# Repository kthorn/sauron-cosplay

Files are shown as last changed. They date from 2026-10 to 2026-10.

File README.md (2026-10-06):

# Child-sized Sauron mace

A **carrying/photo prop, not a striking toy**, sized for a 4′8″ child: **889 mm / 35 inches overall**, six EVA blades, nominal ¾-inch PVC, and a multi-tapered printed blade holder in **two stacked sections**, split **perpendicular to the handle axis**. These dimensions already represent approximately **¾ scale**; do not scale the STLs down again. Blade design **D ("spiked")**, adapted from the United Cutlery PD4646 drawing: sturdy body, spear tip, a round bite and a barbed opening open to the shaft, a hooked outer spike and a crescent base horn. An adaptation, not a film-exact tracing. References and fact/design distinctions: [SOURCES.md](file:///home/kurtt/sauron-cosplay/SOURCES.md) (`/home/kurtt/sauron-cosplay/SOURCES.md`).

## Foam helmet paper templates

Original, more movie-like **layered face plates and all six crown spires**, provisionally sized for a **540 mm headband**. These are **paper-fit design drawings, not measured or foam-ready patterns**. No printed helmet shell is needed.

- [US Letter PDF — five pages](file:///home/kurtt/sauron-cosplay/patterns/helmet/helmet-letter.pdf): `/home/kurtt/sauron-cosplay/patterns/helmet/helmet-letter.pdf`
- [A4 PDF — five pages](file:///home/kurtt/sauron-cosplay/patterns/helmet/helmet-a4.pdf): `/home/kurtt/sauron-cosplay/patterns/helmet/helmet-a4.pdf`
- [Preview, cut list, paper assembly, and scaling instructions](file:///home/kurtt/sauron-cosplay/patterns/helmet/README.md): `/home/kurtt/sauron-cosplay/patterns/helmet/README.md`

Print at **Actual Size / 100%** and check each 100 mm ruler. Pages 1–4 are cutting sheets; page 5 is the assembly key, **not a cutting template**. All parts fit on individual sheets at the supplied size. Full-size editable SVG masters are in `patterns/helmet/`. Paper-fit before EVA; eye position needs separate checking, and helmet sizing does not use the mace's 75% scale. Mace files and regeneration commands below remain separate and unchanged by this drawing set.

## Files

All files are under `/home/kurtt/sauron-cosplay`:

| File | Use |
|---|---|
| `mace.scad` | Editable canonical geometry; default view is assembly |
| `patterns/blade.svg` | Full-size editable pattern, 150 × 351 mm canvas; use tiled PDFs for home printing |
| `patterns/blade-a4-01.pdf`, `blade-a4-02.pdf` | **Two A4 sheets**, 210 × 297 mm each |
| `patterns/blade-letter-01.pdf`, `blade-letter-02.pdf` | **Two US Letter sheets**, 215.9 × 279.4 mm each |
| Matching numbered `.svg` files | Editable versions of the tiled sheets |
| `prints/fit-coupon.stl` | Print **one first** to test real pipe/foam fit |
| `prints/holder-lower.stl` | Print **one**, upright: lower hexagonal holder section, approximately 123 mm tall plus three 6 mm alignment pins on top |
| `prints/holder-upper.stl` | Print **one**, upright: upper hexagonal section with integrated pointed cone and three matching pin holes in its bed face, approximately 123 mm tall |
| `prints/holder.stl` | Complete approximately 246 mm holder for reference/larger printers; **too tall upright for the A1 mini** |
| `prints/adapter.stl` | Optional original ring; print two **instead of** the tapered holder |
| `patterns/manifest.json` | Parameters, holder profile/split, source fingerprints, common tile origins and owned generated files |
| `export.py`, `test_mace.py` | Regeneration and executable verification |

## Tools and regeneration

Verified here with **OpenSCAD 2021.01, Poppler 24.02.0, CairoSVG 2.9.0**. Use the Python interpreter that has CairoSVG installed (here `/home/kurtt/miniforge3/bin/python3`).

```bash
sudo apt-get install openscad poppler-utils
python3 -c 'import cairosvg'
cd /home/kurtt/sauron-cosplay
python3 export.py
python3 export.py --check
python3 -m unittest -v
openscad mace.scad
```

Measure your actual pipe OD and foam thickness before fitting. Example:

```bash
python3 export.py --set pipe_od=27 --set foam_thickness=12
python3 export.py --out "/path/with spaces"
```

`--set` overrides apply to that export, not to the saved SCAD defaults. For a matching interactive preview, set the same values in OpenSCAD's Customizer or edit `mace.scad`; edit SCAD for persistent changes. Commands can also use the script's absolute path from another cwd; default output remains this project folder. `OPENSCAD` and `PDFTOCAIRO` may select alternate executable paths. `--check` checks saved outputs without regenerating them; source edits require regeneration. Invalid sizes, missing tools and failed verification stop publication. Regeneration removes only obsolete manifest-owned files and refuses unowned filename collisions or unsafe/symlink paths.

Public millimeter parameters: `overall_length`, `blade_length`, `head_radius`, `pipe_od`, `bore_clearance`, `foam_thickness`, `slot_clearance`, `adapter_od`, `adapter_height`, `slot_root_radius`, `cover_allowance`, `land_allowance`, `coupon_height`, `tip_od`, `tip_overlap`, `tip_extension`, `tip_end_radius`, `crown_recess`, `pin_d`, `pin_length`, `pin_clearance`, `pommel_od`, `pommel_height`, `pommel_extension`. Bore clearance is on **diameter**; slot clearance is on **total width**, not per side. Changing blade length scales stations but keeps land height independent of that scale. `crown_recess` defaults to 12 mm below the EVA blade tips; `tip_end_radius` defaults to 4 mm. `tip_extension` retains the 35 mm PVC-to-blade-tip setback. `tip_od` and `tip_overlap` describe only the optional legacy foam top cap (`ring_assembly` preview). Other dimensions can require more pages; use the whole numbered set, including the caption gutter on wide heads. Incompatible core, cap, covering or neighboring-blade sizes are rejected.

## Print and tape the blade pattern

1. Choose **either the two A4 PDFs or the two Letter PDFs**, not a mixture. Print at **100% / Actual Size**, with Fit/Shrink disabled.
2. Measure the red **100 mm bar** on both sheets before trimming. Black solid lines are cuts; dashed blue lines/boxes are mounting references **not cuts**; gray crosses are alignment marks; green dash-dot lines are bevel guides, **not cuts**. These line styles remain distinguishable in grayscale.
3. Trim the **bottom 30 mm from page 1** and the **top 25 mm from page 2**. Align both gray crosses in the **10 mm overlap**, then tape. Do not simply butt whole page edges together. Discard the trimmed headers/footers only after the ruler check.
4. Check the assembled black outline: **295.275 mm tip-to-base × 46.5 mm radial width**. Cut on the black line's center. Transfer **six identical blades** onto measured 10 mm EVA. No rigid blade reinforcements.
5. Bevel using the **green dash-dot line**, 6 mm in from each exposed edge (not along the straight root edge, which sits in the grooves). It is a marking line, **not a cut**: cut the blade out square on the black line, transfer the green line to **both faces** (prick through the paper or measure 6 mm in), then carve or sand from the line to the edge on each face, leaving about a 2 mm flat in the middle of the edge. With 10 mm foam that removes about 4 mm per face, roughly a 35° bevel. Where the line stops short of a point (tip, spike, barb, horn), taper the bevel out to the point. For thinner foam, regenerate with a smaller inset, e.g. `python3 export.py --bevel 4`.
6. Test-cut one blade from scrap EVA first and check flex across the bridges beside the openings, the barb, the hooked spike and the horn. Round over every point by hand.

## Print and fit the tapered holder

The **hexagonal spindle** follows the drawing's 380 mm core: a flared base collar, a narrow waist, one widest swell, then a long taper to the crown, placed to match blade D: the collar on D's base root, the waist inside its lower opening, the swell over its solid middle root, and the taper through its round bite, so the core shows through both openings as in the drawing. Blades sit at its **six vertices**, but it is grooved **only where a blade meets the core**: D's three root contacts, about **37–67, 117–179 and 207–243 mm** from the blade base. Each groove floor follows the blade's inner edge; between the grooves the hexagon is solid. The upper section includes a **printed cone ending in a hexagonal point** (no ball tip), ending approximately **12 mm below the protruding EVA blade tips**. This is a simplified interpretation of the drawing, not a precision replica. The existing **295.275 mm blades, 180 mm station spacing, and PVC cut length are unchanged**. The complete holder is approximately **246 mm tall**, split perpendicular to the handle axis into **two approximately 123 mm sections**, joined end-to-end around the PVC. Three printed **4 mm alignment pins** on the lower section's top face (6 mm long, on the hexagon-flat directions, clear of the grooves; the joint falls inside the middle groove zone) drop into **4.4 mm blind holes** in the upper section's bed face; no screws or other hardware.

Default dimensions: pipe OD **26.67**, bore **27.17** (+0.50 diameter); foam **10**, slot **10.3** (+0.30 total width), slot roots **18.5 mm from the axis**. The swell reaches **60 mm nominal diameter** (collar 54 mm); grooves remove those vertices, so do not rescale the meshes to force a 60 mm bounding box. The waist leaves approximately **3.30 mm minimum wall** outside the cylindrical bore. The upper bore stops above the PVC end with 1 mm axial slack, then closes with a **45° internal conical ceiling**; the pointed crown above it is solid. Both sections fit well within the A1 mini's **180 × 180 × 180 mm** volume, with room for a brim.

1. Print the existing **5 mm fit coupon first**, upright. Test the real bare PVC and foam; adjust `pipe_od`, `bore_clearance`, `foam_thickness`, and `slot_clearance` rather than forcing a fit.
2. Print **one lower and one upper section**, separately or side-by-side. Import at **100% scale**, with the bore vertical and the exported Z=0 face on the bed. Keep their exported orientation; the sections are **not identical**.
3. Defaults use ascending tapers and the internal bore ceiling no steeper than approximately 45°: **no supports are intended**. The lower bore goes through; the upper bore opens only at the bottom. Inspect Bambu Studio's layer preview before printing, especially if dimensions change. PLA or PETG, 0.2 mm layers, 3–4 perimeters, 15–20% infill, and a small brim are starting settings, not strength certification.
4. Dry-fit both pieces end-to-end on the PVC, **lower first**, with all six grooves aligned and the three pins seated in the upper section's holes. If the pins bind, trim them lightly or regenerate with a larger `pin_clearance`; do not force the joint. Install **both as printed, with their bed faces toward the pommel**: the upper section's bed face is the joint, and its cone points toward the blade tips. Their flat transverse joint is located at **160.138 mm from the blade base**. The collar sits at the 45 mm station; the 60 mm swell is centered about 150 mm from the blade base, over the middle root. The PVC aligns the bores; the alignment pins establish rotation. Do not twist or force the pieces with blades fitted.
5. Bond the sections to the PVC and to each other only after checking adhesive compatibility on scraps. The butt joint is not a load-rated connection. Pad exposed hard surfaces after fitting without narrowing the grooves.

The original `adapter.stl` remains an optional lighter two-ring alternative. Do not install those rings inside the new holder. The full `holder.stl` is one connected piece but is **not the A1 mini print file**. The new holder adds plastic compared with the rings; weigh the finished mockup and check carrying comfort.

## PVC layout and assembly (defaults)

The **provisional PVC cut is 839 mm**, not 889. Dry-fit before the final cut/glue. Layout includes 15 mm solid foam below the lower pipe end. The EVA blades extend 35 mm above the upper pipe end; the pointed printed cone ends about 12 mm below those blade tips. The EVA surround is **not an impact-protection guarantee**. The top is open approximately **60 mm across**: a finger, nose or eye can reach the hard crown **without touching or deforming the foam**. Keep the head away from faces; do not let children look into or poke the crown.

| Feature | From the prop's lowest foam extremity | From the lower PVC cut end |
|---|---:|---:|
| PVC lower/upper ends | 15 / 854 mm | 0 / 839 mm |
| Blade base | 593.725 mm | 578.725 mm |
| Lower holder bottom | 630.725 mm | **615.725 mm** |
| Lower blade station center | 638.725 mm | 623.725 mm |
| Holder section joint | 753.863 mm | **738.863 mm** |
| Upper blade station center | 818.725 mm | 803.725 mm |
| Rounded printed crown tip (nominal) | 877 mm | **862 mm** |
| EVA blade tips | 889 mm | 874 mm |

If length/cap settings change, use the new manifest's `pipe_span`, `blade_base`, `stations` and parameters instead of these default marks.

1. Have an adult cut/deburr the PVC. Mark the holder's lower bottom and section joint using the table. Slip the lower and upper sections onto **bare PVC**, **bed faces toward the pommel and cone toward the blade tips**, seating the three pins in their holes, which aligns the six grooves, and closing the transverse joint.
2. Dry-fit one blade radially into the aligned grooves. Its root stops at 18.5 mm radius. Existing mounting bands remain **34–56 and 214–236 mm** from the blade base; station centers remain **45 and 225 mm**. Grooves are cut wherever the blade's inner edge would otherwise enter the spindle, so the relieved edge between the bands clears it. Check flop and clearance before cutting/gluing the other five. Thicker foam is a tuning option; regenerate the slots and recheck weight/fit.
3. Fit all six, then glue permanently using manufacturer-compatible adhesives **tested on scraps** for EVA, PVC and the chosen print plastic. Plumbing PVC solvent cement is **not assumed to bond PLA/PETG**. Follow adhesive ventilation, curing and handling directions; keep coating off bond surfaces until joined.
4. The printed crown is already part of the upper section; **do not fit the old foam top cap over it**. Check that the pipe seats without force and that the crown stays approximately 12 mm below the EVA tips along the handle axis. This axial recess does not enclose the tip or prevent direct contact through the open head. For the optional two-ring alternative only, use `ring_assembly` to preview the original foam top-cap envelope: 36 mm OD, 15 mm sleeve overlap and 35 mm solid foam above the PVC, with a blunt 4 mm-radius tip.
5. Make the **pommel cap from EVA**, 40 mm OD × 40 mm long. Its cavity opens from above, is 25 mm deep, and leaves **15 mm solid foam beneath the PVC**. Round the outside without adding to overall length.
6. Bond the foam pommel only after an adhesion/retention trial. Wrap the shaft with approximately **3 mm radial foam**, **not beneath the holder bore or pommel sleeve**; the first 25 mm of PVC seats in the pommel. Leave the PVC bare from the holder's lower bottom through the upper pipe end. Pad exposed holder edges without obstructing blade grooves; the pointed crown intentionally remains printed plastic; lightly sand the point blunt if wanted. Check blade retention and spacing so it stays recessed. Foam blades can bend or tear and must not be relied on to make a hard crown safe to strike with.

## What was verified / what was not

Digital checks: blade D's polygon is simple, its openings stay open to the shaft with at least 16 mm of foam beside them, and green bevel guides on every sheet lie inside the outline and off the root edge. Actual SVG outline **295.275 × 46.5 mm**; A4 PDF reconstruction approximately **295.27538 × 46.49914 mm**, Letter **295.27431 × 46.49914 mm** (all within 0.1 mm). The original ring and coupon remain closed connected meshes with correct 16/5 mm height, through-bore and six open slots. The whole tapered holder and both upright sections are also checked for closure/connectivity, correct cylindrical bore and conical ceiling, six vertex grooves whose floors follow the blade inner edge, with solid hexagon vertices outside the contact regions (including width checks on both sides at the blade stations, widest swell and each section's deepest groove; unverifiable groove widths are rejected), the hexagonal spindle profile, pointed crown, and approximately 246/123/123 mm heights. Section bounding boxes are checked against a **175 mm** envelope, reserving 5 mm total for a brim on the 180 mm printer. An actual CAD intersection checks the foam against the new holder, excluding nominal root-face contact. Reference centers **and band boundaries** are checked in SVG/PDF physical coordinates. The real CLI rejects 90%-scaled cut outlines while their calibration bars remain unchanged, then passes after restoration. Model/assembly and both paper-format previews were inspected; no interactive GUI editing or physical fabrication was performed.

Radial/sector/land assertions bound the entire blade foam outside the covered core/cap and within non-overlapping 60° sectors. Radial insertion keeps these clearances; seated roots pass through wider open slots. This is geometric clearance, **not** a load, cushioning, adhesive or impact test.

**Before the child uses it:** test coupon fit and compatible adhesives; assemble one blade to check flop; check holder-joint, blade and pommel retention, crown recession, and that all other hard endpoints/fittings are covered; weigh the completed mockup and check the child's carrying comfort. Check the venue's rigid-core prop rules. Adult supervision for cutting, printing, glue, heat and paint. **Do not swing or strike with this prop.** Foam dimensions are provisional, not an impact-protection rating.

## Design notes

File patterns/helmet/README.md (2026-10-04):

# Sauron helmet — printable paper-fit templates

**Provisional nominal 540 mm headband, not measured child fit. Start with paper, not EVA.** Original simplified drawings based on production-helmet photographs: layered face plates and six principal crown spires, without intricate engraving or a closed shell.

## Print these

- [US Letter PDF — five pages](file:///home/kurtt/sauron-cosplay/patterns/helmet/helmet-letter.pdf)
  `/home/kurtt/sauron-cosplay/patterns/helmet/helmet-letter.pdf`
- [A4 PDF — five pages](file:///home/kurtt/sauron-cosplay/patterns/helmet/helmet-a4.pdf)
  `/home/kurtt/sauron-cosplay/patterns/helmet/helmet-a4.pdf`
- [Assembled appearance and crown-position preview](file:///home/kurtt/sauron-cosplay/patterns/helmet/preview.png)
  `/home/kurtt/sauron-cosplay/patterns/helmet/preview.png`

Choose the PDF matching your paper. Print **Actual Size / 100%**, with Fit/Shrink disabled. Check the **100 mm red ruler on every page** before cutting. Pages 1–4 are cutting sheets; page 5 is an assembly illustration, **not a cutting template**. Each part fits on one sheet: no page trimming/taping is required at this size.

The five numbered `.svg` files beside this README are the full-size editable drawing masters, with millimeter dimensions. They use Letter canvases; the A4 PDF changes the paper size, **not the artwork scale**. The assembly illustration is schematic, with wrapped side plates compressed in front view; do not measure or trace its silhouette for cutting.

## Cut list

Cut one master per distinct outline, then trace repeats onto spare paper. For a mirrored pair, flip the master over for the second piece; alternatively print selected cutting sheets again. Black internal openings in A and B are cuts too.

| Sheet | ID | Part | Quantity | Eventual foam starting thickness, after paper fit |
|---|---|---|---:|---|
| 1 | A | Eye/brow frame | 1 | 4 mm |
| 1 | E | Brow ridge | 2 mirrored | 2 mm |
| 1 | G | Forehead accent | 1 | 2 mm |
| 1 | K | Forehead support patch | 1 | Soft 4–6 mm |
| 1 | L | Temple support tab | 2 | Soft 4–6 mm |
| 2 | B | Split center/nose ridge, with breathing slot | 1 | 4 mm |
| 2 | C | Swept cheek plate | 2 mirrored | 4 mm |
| 2 | C2 | Cheek inset | 2 mirrored | 2 mm |
| 3 | D | Temple plate | 2 mirrored | 4 mm |
| 3 | S1 | Central front spire | 1 | 4 mm |
| 3 | S2 | Central rear spire | 1 | 4 mm |
| 4 | S3 | Tall side spire | 2 mirrored | 4 mm |
| 4 | S4 | Short forward spire | 2 mirrored | 4 mm |
| 4 | H | Paper support strip | 6 | **Paper fitting aid; final support is soft webbing** |

Six spires total: **S1 + S2 + 2 × S3 + 2 × S4**. Their 25 mm roots are already included in the outlines. Do not add another root allowance. All foam thicknesses are provisional; physical stiffness, fit, and weight have not been tested.

## Line key

- **Solid black:** cut outline and openings.
- **Dashed blue:** placement or bond/overlap guides; do not cut.
- **Dash-dot green:** shallow forming fold for paper; do not cut through foam later.
- **Gray labeled diamonds:** match the same label across parts. These are adjustable lap placements, not precision edge-to-edge joints.

## First paper assembly

1. Make the support before the face. Four H strips (165 mm each) joined at three 20 mm overlaps give **600 mm**. Close with an adjustable **60 mm rear overlap** for a nominal **540 mm** loop. Two more H strips joined with 20 mm overlap give a **310 mm** top strap; provisional 20 mm end attachments leave **270 mm** over the head. Adjust on the child, keep it loose, and keep the rear overlap reachable. No chin strap.
2. Gently curve A around the face. Match A/B to place B on its center and A/C to place both C cheeks. Wrap cheeks/temples around the face; do not just add their full flat width to the front. Cut A's eyes and B's breathing slot. Tape only B's upper A/B area, leaving its lower portion free; use the short green guide below eye level to angle it gently forward, away from nose/mouth pressure.
3. Fold K at its green center line: center its face half behind A's forehead zone and tape its band half to the front band, adjusting the fold/curvature for forehead stand-off. Turn each L 90 degrees so its 25 × 20 mm half matches A's 20 × 25 mm blue side box; tape that half directly behind A and fold the other half toward the temple band. Fit L before D, then add D behind the sides using A/D without covering L's fold or band half. Use broad outside tape areas; do not hang the face from temple tabs alone. The top strap supports height but does not prove resistance to tipping. These folds do not guarantee nose clearance; fit the wearer and recheck tipping whenever stand-off changes.
4. Add E using A/E, G using B/G, and C2 using **both** C2.1 and C2.2 diamonds. Decorative overlays are optional; do not cover sight or breathing openings.
5. Form the spires into shallow open-backed V sections along the green guides, roughly 120° as a paper starting point. Curve/fold each 25 mm root to the band and tape it in the crown position shown on page 5. Add them one at a time and check balance. S2 must not tape across the rear adjustment/removal opening. Tape or round all sharp paper corners before fitting.
6. With an adult supervising, start stationary and then walk on a clear flat floor. Check floor/side vision, normal speech/breathing, nose/ear/forehead pressure, head turns/downward looking, glasses clearance if needed, shoulder clearance, crown clearance, and **unaided removal**. Stop for slipping, obstructed sight, discomfort, dizziness, or breathing difficulty. No running or stairs in this trial.

Mark corrections on the paper: eye centers, band length, cheek length, crown height, and attachment positions. A paper fit does not establish foam fit, cured bond retention, weight, point softness, or heat comfort. Recheck these independently in a future foam prototype. This is not protective headgear or a safety certification.

## Scaling later

At the supplied size, the ruler measures 100 mm. For an initial uniform paper rescale to a measured circumference H, start with **H / 540 × 100%**; the ruler then measures **100 × H / 540 mm**. This is only a starting point: eye spacing and cheek/shoulder clearance need separate fitting, not circumference scaling.

For enlargement use a PDF viewer's **Poster / Tile Scale** printing, or resize SVG canvas and artwork together in a vector editor. Ordinary custom scaling on a fixed page can clip pieces near the margins. Keep every cutting sheet at the same intended scale, verify the appropriately scaled rulers, and check for complete outlines. Do not use Fit/Shrink as a substitute for a known scale.

## Checks and limits

All 14 distinct component outlines were checked against their declared flat dimensions, including all six spires through their quantities. The actual final PDF cutting paths, blue placement paths, green forming guides, page sizes, and red rulers were compared with the SVG masters within 0.1 mm. A deliberate copied 90%-scale cutting-path corruption was rejected with its 100 mm ruler unchanged. Drawings were rendered and visually inspected. No physical assembly, wearing test, or film-exact reconstruction has been verified.

Detailed design, fitting limits, and adult-only foam work guidance: [design/build guide](file:///home/kurtt/sauron-cosplay/docs/superpowers/specs/2026-10-03-sauron-helmet-design.md).

`/home/kurtt/sauron-cosplay/docs/superpowers/specs/2026-10-03-sauron-helmet-design.md`

The SVGs—not a temporary authoring script—are the retained masters. No OpenSCAD model or permanent pattern generator was added. After editing a master, regenerate its PDF with installed CairoSVG, merge pages with installed Poppler `pdfunite`, and recheck actual PDF geometry before replacing a print pack.

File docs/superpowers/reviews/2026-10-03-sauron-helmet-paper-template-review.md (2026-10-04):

# Sauron paper templates — revision 2 review and verification

2026-10-03. Subject: original provisional paper-fit design drawings, not fitted foam fabrication or protective headgear. Parent authored/refined the documents and drawings; independent reviewer was read-only. No permanent product code or generator was added. SVGs are the retained masters.

## Review routing and scope

- Requester: OpenAI (`PI_PROVIDER=openai-codex`, `PI_MODEL=gpt-6.1-sol`). Required opposite family: Anthropic.
- Paseo agent: `0411aa0d-d3f7-4eac-b6c3-b96a4f0939dc`, cwd `/home/kurtt/sauron-cosplay`; no Git branch/ref/worktree.
- Canonical selection: `claude/claude-opus-5-5`, thinking `medium`, Plan Mode; actual model/effort/mode verified with `paseo inspect`.
- Evidence supplied: exact spec and pattern README, artifact hashes, rendered four-sheet contact image, assembly preview, production-helmet photograph, and parent physical-export verification results. Reviewer used no tools and did not independently open PDFs or confirm hashes.
- Three scrutiny areas: drawing/assembly contracts, child wearability boundaries, and printing/scaling correctness.
- Initial review plus one focused follow-up, same model/effort. First 120-second wait window elapsed while agent remained running with no error or permission request; subsequent waits returned `idle` and actual final responses were consumed. No route substitution.

Initial spec SHA256: `0b8590c9d465c1dcdfc26b38b476de809d3f1a52b45f2434a83e2522084808ef`.
Corrected reviewed spec SHA256: `514c7fe111a717fdbd355d4d9e93409dcb61457c50be77aea3933cac9e3b7f02`.
Corrected reviewed pattern README SHA256: `f367e110d07bfcda0d924104291474c485026230c0f6c42f4f85d6ebf64b5609`.

## Findings and dispositions

1. **L temple-tab placement unspecified — accepted.** A's two blue side boxes now explicitly say “L behind”; sheet 1 specifies a quarter-turn and sheet 5 names those support zones. Both documents state that a rotated 25 × 20 mm half matches the 20 × 25 mm box, attaches directly behind A, and folds toward the band. Fit L before decorative D and keep D off the fold/free band connection. Do not make D the sole support connection. Follow-up: resolved.
2. **G forehead accent slightly covered inner eye corners — verified and fixed.** Parent exact polygon check reproduced the original overlap, then checked the corrected nominal flat placement. Moved G corners `(11,35)` and `(29,35)` inward to `(14,35)` and `(26,35)`, leaving its 40 × 47 mm bounds and anchor unchanged. Both eye polygons now clear it; curved/worn clearance remains unverified. Follow-up: resolved for the drawing, with only about 1 mm nominal inner-corner margin.
3. **Forehead/nose stand-off under-specified — accepted as a practical documentation gap, not proof of physical failure.** Added K's center forming guide and face/band half labels, and B's below-eye forming guide. Documents now instruct adjustable forehead stand-off, upper-only B attachment, free lower B angled forward, physical clearance checks, and retesting tipping when the gap changes. No fixed spacer depth or guaranteed wearability was invented. Follow-up: resolved as a wording issue.

Optional footer concern addressed: caption moved from y=273 to y=269 mm, leaving at least 10.4 mm below its baseline on Letter; ruler unchanged. Other optional refinements were not blockers and did not warrant extra machinery or review rounds.

Terminal reviewer verdict: **“No supported substantive findings.”** Stop the refinement pass. Subsequent status/link/checklist additions are administrative, not changed fabrication geometry.

## Parent executable and visual verification

One-off document verification reused the existing `export.py` `_geometry`, `_segments`, `_bounds`, and `_same_segments` helpers; no parallel permanent SVG/PDF parser was created.

- All 14 distinct pieces matched independently specified flat bounding dimensions. Spire quantities total six; H quantity is six.
- Every cutting path was inside both paper formats: x ≥ 10, x ≤ 200, 30 ≤ y ≤ 253 mm.
- `pdfinfo` confirmed two five-page packs: Letter 215.9 × 279.4 mm and A4 210 × 297 mm.
- Each page of the final merged PDFs was converted with `pdftocairo -svg -f N -l N -noshrink -nocenter`; actual black cutting paths, blue placement paths, green forming guides (normalized into the existing verifier's reference channel), and red calibration paths matched the SVG masters within 0.1 mm. Page dimensions matched within 0.01 mm.
- Every actual PDF ruler measured 100 mm; `pdftotext -layout` confirmed five provisional warnings and five ruler captions in each pack.
- An intentionally copied 90%-scale A outline failed the physical cutting-path comparison while its 100 mm ruler remained unchanged. Original masters/PDFs were not mutated by the probe.
- Separate eye-overlay regression reproduced the old G/eye intersection and confirmed its absence after the inward-corner correction, at nominal flat placement only.
- Masters, both paper-format PDF examples, and assembly preview were rendered and visually inspected; revised support labels/forming guides checked after corrections.
- Final geometry checks and local Markdown link-target checks were rerun after corrections. Mace source/generated files were outside this session's changes; another session independently owns them.

## Reviewed final artifact hashes

| File under `patterns/helmet/` | SHA256 |
|---|---|
| `01-frame.svg` | `af767f6572b9c0734890af57feba7dbcecb2cd3ec6c8a10f723a10159c24d267` |
| `02-face.svg` | `3382725252666c72c9f201cab9dcb63478ff3045fbe153ee0186c93ea1d81522` |
| `03-center-spires.svg` | `dbb1086b69499819ac96594434a216da752934dc15a610ade25f1d5ef8df858a` |
| `04-paired-spires.svg` | `50a0ab4562e5bcb87f186713d14b202100e7bd1f8ca970972d0763f88d0cbb6c` |
| `05-assembly.svg` | `e8821adcfc7a0130f1c3a7f7496c50643de46906950a3c01eefae62f4a33a28b` |
| `helmet-a4.pdf` | `816ec15260dfc9612cf15b0aa74d6644776d33525473bf8debeb7226a0268954` |
| `helmet-letter.pdf` | `7b51f6a6edb09eb445059b762a55add4034b21f2655fb927945136eabe70dca1` |
| `preview.png` | `f3e375338d18b0d90b044d5efdacd2b230ce3d6e872816292a54d29f6426f05b` |

## Remaining limitations

User silhouette approval and paper fitting are pending. Nominal 540 mm circumference and 60 mm eye spacing are not child measurements. Tight nominal overlay clearance, folded support geometry, six-spire balance, and actual nose/shoulder/door clearance require the physical trial. Paper success does not establish EVA stiffness, forming, bond retention, finished weight, heat comfort, or safe impact performance. Do not go straight from this document review to foam construction without those fit checks.

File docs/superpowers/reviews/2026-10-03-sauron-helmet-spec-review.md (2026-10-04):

# Sauron foam helmet — independent design review record

Date: 2026-10-03. Mode: parent-authorized document drafting/refinement, independent **read-only text-only review**. No physical build, fitted pattern, CAD, video, or executable changes were reviewed.

## Subject and routing

- Subject: `/home/kurtt/sauron-cosplay/docs/superpowers/specs/2026-10-03-sauron-helmet-design.md`.
- Requesting family: OpenAI; session environment `PI_PROVIDER=openai-codex`, `PI_MODEL=gpt-6.1-sol`.
- Required opposite family: Anthropic.
- Runner: Paseo agent `51bccd6a-b97b-40f8-bc81-0c39e72f9e23`, cwd `/home/kurtt/sauron-cosplay`, no Git branch/ref/worktree.
- Requested canonical model: `claude/claude-opus-5-5`, thinking `medium`, Plan Mode. `paseo inspect` verified actual model `claude-opus-5-5`, effort `medium`, mode `plan`.
- Initial subject SHA256: `4f63727c2ed662a6d0e8575330925227c17a8a59cb7f75f2bf60f03335b8ea0f`.
- Corrected subject SHA256: `ba12831d190e6b9e003796fea622254f6dd949b2b10fd2044b9f4ec2392024d3`.
- Budget: three substantive areas—sizing/assembly, child wearability/safety, evidence/pattern reuse. Initial pass plus one focused follow-up with the same agent/model/effort. Both `paseo wait` results were `idle`; actual responses were consumed. No tools were used by the reviewer.

## Findings and parent disposition

### 1. Under-specified facade support and forward tipping

Location: component layout and foam assembly sequence. Reviewer identified an ambiguous forehead attachment: a parent might hang the facade from temple tabs alone. A side-to-side strap does not by itself establish pitch stability under the front-heavy foam load.

**Accepted the specification gap**, not a proven claim that every such strap layout will fail. Parent added a broad soft forehead attachment patch, required forehead plus both temple connections, and explicitly separated height support from pitch stability. The cured brow/support assembly is now tested first, then cheeks and points added incrementally. Forward tipping stops work for redesign; no painful tightening, chin strap, or unapproved additional support system is prescribed.

Follow-up: reviewer confirmed this ambiguity is resolved and physical stability remains appropriately unverified.

### 2. Unsupported attribution of resizing guidance

Location: reference evidence paragraph. The first review brief omitted resizing from its summary of verified tutorial evidence, so the reviewer questioned its attribution to the author.

**Rejected on verified source evidence.** The fetched tutorial text explicitly states: “Depending on your head size you may have to shrink or enlarge the pieces.” Source: https://thewoodlandelf.com/sauron-costume-part-2-the-helmet/; session fetch result `musykwfiqp8799`, URL index 0. No substantive body change was needed. The source also explicitly describes deliberate simplification.

Follow-up: reviewer withdrew this finding after receiving the exact source passage.

## Terminal verdict and limits

Reviewer's follow-up verdict: **“No supported substantive findings.”** Stop this review pass. Subsequent review-status/checklist additions are administrative; the reviewed fabrication design is unchanged.

This is not certification of fit, comfort, safety, adhesive retention, or suitable pattern scale. User review, actual measurements, paper fitting, incremental foam fitting, and finished-costume wear checks remain outstanding. Mace source/generated files were not part of this assignment. No source PDF was redistributed.

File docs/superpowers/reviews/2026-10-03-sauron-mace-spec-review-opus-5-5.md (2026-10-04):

# Sauron Mace Spec Review (Opus 5.5, read-only)

**Subject:** `docs/superpowers/specs/2026-10-03-sauron-mace-design.md` (SHA256 `1d7ebf40…9b50`), reviewed from the supplied text only. No tools were run. This is not physical validation.

**Default geometry checked by hand:**
- **Bore-to-slot wall:** bore radius 13.585 against slot floor 18.5 gives a minimum wall of 4.915, which meets the ≥3 requirement.
- **Wall between slots:** at r = 18.5, each 10.5 slot subtends about 33° of the 60° pitch, leaving about 8.7 mm of arc between slots.
- **Slot engagement:** 11.5 radial (18.5 to 30).
- **Adapter positions:** both adapters sit fully on the PVC. The upper adapter top is at about 826.7 and the PVC ends at 854.
- **Scale arithmetic:** 0.75 × 46.375 in = 883.44 mm, and 0.75 × 15.5 in = 295.275 mm. The 889 total and the 839 pipe length (15 to 854) are internally consistent.

## Findings

**1. No minimum inner-radius (clearance) rule for the blade profile.**
- **Evidence:** The spec requires a "relieved inner edge", and the land is at radial 18.5. Acceptance 1 bounds only "max 65 radial". Blades "slide inward radially".
- **Consequence:** Nothing stops the outline, outside the lands, from going inside the PVC radius (13.335) or the covering/tip cap. That blade could not be inserted radially. Above the pipe end (854 to 889), inward-swept tips could also collide with each other or with the tip cap. The "no intersecting adjacent blades" check does not catch blade-to-pipe or blade-to-cap intrusion.
- **Smallest fix:** Add a profile constraint and check. Inner edge radius must be ≥ 18.5 within the adapter axial spans. Elsewhere along the pipe it must be ≥ pipe OD/2 plus a covering allowance. Above the PVC it must be ≥ the tip-cap radius. Out-of-range values are rejected.

**2. Tip extension and pommel are load-bearing in the layout but have no defined geometry.**
- **Evidence:** "Overall 889 incl foam pommel/tip", "Foam tip extends 35 beyond PVC", and "soft 35mm tip extension". The outputs list contains no cap or pommel part, and the blade tips also end at 889.
- **Consequence:** The child-safety soft end and the overall length rely on an unspecified part. That part must fit inside the six blade inner edges, a gap of less than about 18.5 radius. That leaves at most about 5 mm of cap wall over a 13.3 mm pipe radius, which may not be a usable soft cap.
- **Smallest fix:** Specify the cap and pommel envelope (OD, length, material, attachment) as parameters in `mace.scad`. Include them in the clearance check from finding 1 and in the README fit sequence. They do not need patterns.

**3. Reference marks cannot leave OpenSCAD with distinct styles without duplicating coordinates.**
- **Evidence:** The script "NEVER duplicates blade coordinates", yet the patterns need "distinct cut/reference styles" with bands and station centers as "REFERENCE marks". OpenSCAD SVG export produces unstyled geometry from a single 2D mode.
- **Consequence:** The implementer will either recompute station and land positions in Python, breaking the single-source rule, or ship patterns without distinguishable reference marks.
- **Smallest fix:** Define a separate SCAD 2D mode, such as `blade_marks`, exported as its own SVG. Alternatively, have the script parse `echo()`'d derived values. `export.py` then only applies styles and tiles the pages.

**4. Scale checks don't measure the exported outline itself.**
- **Evidence:** Acceptance 1 checks the blade's dimensions. Acceptance 5 checks page dimensions, overlap, coverage, and the 100 mm bar.
- **Consequence:** The calibration bar is drawn by the export script, so it can be correct while the imported SCAD outline is mis-scaled. A px-vs-mm or 96-DPI CairoSVG unit error would pass every check and produce wrong-size foam cuts.
- **Smallest fix:** In the final SVG and PDF coordinates, assert that the outline bounding box equals 295.275 axial by 46.5 radial (18.5 to 65), within about 0.1 mm. Assert the bar is exactly 100 mm in the same space. Make the deliberate-failure check (acceptance 6) include a unit or scale corruption.

## Residual risks (not findings)
- **Untested physical fit:** EVA thickness variation, print tolerance, and PLA/PETG–EVA adhesion are unproven until the coupon and scrap tests are done, as the spec already acknowledges.
- **Blade flop:** about 158 mm of unsupported blade between the lands may flop. The one-blade test covers this.
- **Unverified tooling:** OpenSCAD is absent, so no STL or SVG behavior has been verified.

## Substantive findings
1. Blade inner-edge minimum radius and clearance against the pipe, cover and tip cap is unconstrained and unchecked.
2. Tip and pommel caps are undefined despite fixing the overall length and soft-end safety, and their fit inside the blade ring is unchecked.
3. Reference-mark export conflicts with the no-duplication rule under OpenSCAD's unstyled SVG output.
4. The exported outline scale is not discriminatingly verified; only the script-drawn calibration bar is checked.

```acceptance-report
{
  "criteriaSatisfied": [
    {
      "id": "criterion-1",
      "status": "satisfied",
      "evidence": "Concise review with four evidence-backed findings (blade inner clearance, undefined tip/pommel cap, reference-mark export vs single-source rule, exported-outline scale check), hand-checked default geometry, and residual risks"
    }
  ],
  "changedFiles": [],
  "testsAddedOrUpdated": [],
  "commandsRun": [],
  "validationOutput": [
    "Hand-checked: core wall 4.915>=3; inter-slot arc ~8.7mm at r18.5; engagement 11.5mm; upper adapter top ~826.7 < PVC end 854; 75% scale values match SOURCES"
  ],
  "residualRisks": [
    "Physical fit/adhesion/flop unverified until coupon and one-blade tests",
    "OpenSCAD not installed; no STL/SVG behavior verified",
    "Review based solely on supplied spec text; SOURCES.md not independently inspected"
  ],
  "noStagedFiles": true,
  "diffSummary": "No files changed; review text returned for host persistence to docs/superpowers/reviews/2026-10-03-sauron-mace-spec-review-opus-5-5.md",
  "reviewFindings": [
    "major: spec Acceptance 1 / Interface - no minimum blade inner-radius clearance vs PVC/cover/tip cap",
    "major: spec Dimensions/layout - 35mm tip and 15mm pommel caps undefined yet set overall length and safety",
    "major: spec Approach/Patterns - reference-mark styling vs no-duplicated-coordinates rule unresolved",
    "major: spec Acceptance 5 - exported outline scale not verified in final SVG/PDF coordinates"
  ],
  "manualNotes": "No-tools read-only run; plan-mode tool workflow not invoked per runner instructions. Final answer is the review artifact."
}
```

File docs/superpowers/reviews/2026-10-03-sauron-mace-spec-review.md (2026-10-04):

# Spec review — blocked before analysis

This is a parent-recorded infrastructure report, **not a completed review or a clean verdict**.

- Run: `49d26970-24ea-4440-a336-921df606a493`
- State: `failed`, confirmed by the supervisor status tool.
- Runner: `claude-code`, external CLI, read-only Plan Mode, no tools.
- Requested and initialized model: `claude-opus-4-6`; requested effort: high.
- Exact failure: `Failed to authenticate: OAuth session expired and could not be refreshed`.
- No model analysis was delivered; API usage was zero. There are no substantive findings to salvage.
- Cwd: `/home/kurtt/sauron-cosplay`.
- Git repository, worktree, branch, and ref: not applicable; the folder is not a Git repository.
- Source/spec fingerprints remained unchanged after the failed run:
  - `SOURCES.md`: `95b8fc3d2a6c000015938f73339c8d0db173d0df8aad06a526a3a15873ead98b`
  - `docs/superpowers/specs/2026-10-03-sauron-mace-design.md`: `1d7ebf4087739624462369d118f5dede5788ff52c5037f5f0b580f015c449b50`
- No CAD implementation or fabrication export has been started.

## Recovery boundary

The owner must re-authenticate Claude Code (`claude auth login`, confirmed available in the CLI help), then authorize a same-protocol retry. This external run cannot be resumed; retry as a new read-only `claude-code` run with the same model/effort and current subject version. Alternatively, ask the owner to approve a different review route. Do not silently switch mechanisms or count this failed run as independent review completion.

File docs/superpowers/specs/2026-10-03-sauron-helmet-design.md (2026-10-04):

# Sauron foam helmet — provisional paper-template design

Status: **paper-fit design study**, not a fitted or foam-ready fabrication pattern. Revision 2, 2026-10-03. The user requested a more movie-like middle ground, explicit spike patterns, and a provisional size that can be changed later. No helmet has been fabricated or wear-tested.

## Purpose and scope

Design original full-size paper cutting drawings for a recognizable Sauron helmet for the same nine-year-old as the mace. Use layered EVA-style face plates and six faceted crown spires, inspired by production-helmet front, side, and rear photographs. Keep an open back/top, a soft adjustable support, generous sight openings, and flexible rounded points. Omit intricate engraving, a closed dome, rigid spike cores, eye mesh, chin straps, and printing hardware.

The deliverable in this revision is **the physical design drawing set for paper fitting and user review**, not a software subsystem or a parametric CAD generator. SVGs are the editable drawing masters. PDF conversion uses existing installed tools; no new product dependencies or permanent generator are needed. No mace source, export contracts, or generated mace files should change.

## Reference and evidence boundaries

Primary reference is the Propstore production helmet, not a tracing of the Woodland Elf PDF. Five photographs were visually inspected. The movie-like features to preserve are the long split lower face, narrow center ridge, angular eye/brow frame, layered swept cheek/temple plates, and faceted spires. The six principal spires are interpreted as a tall side pair, shorter forward pair, central front spire, and central rear spire. Small edge points are decorative, not additional principal spires.

Reference links and inspection limits: [helmet references](file:///home/kurtt/sauron-cosplay/docs/helmet-references.md).

`/home/kurtt/sauron-cosplay/docs/helmet-references.md`

These perspective images are not orthographic drawings or flat developments. Every dimension below is **our provisional design choice**, not a measurement of the prop or this child. Keep links to source photographs/patterns; do not redistribute or trace third-party files. The earlier five-point Woodland Elf-inspired proposal is superseded. Its review record describes that earlier revision, not approval of this new one.

## Provisional size and scaling

| Item | Drawing assumption, not measured fit |
|---|---|
| Headband loop | 540 mm after joining and rear adjustment overlap |
| Eye center spacing | 60 mm nominal; actual sight openings must be located on the wearer |
| Brow frame development | 170 mm wide; shallow wrapping changes its apparent front width |
| Central face ridge | 42 × 210 mm flat outline; narrow through the eye region |
| Main cheek plate | 70 × 196 mm flat outline, cut twice mirrored |
| Tall side spires | 50 × 205 mm, including a 25 mm root; cut twice mirrored |
| Short forward spires | 44 × 155 mm, including a 25 mm root; cut twice mirrored |
| Central front spire | 42 × 185 mm, including a 25 mm root; cut once |
| Central rear spire | 42 × 175 mm, including a 25 mm root; cut once |

A nominal 540 mm circumference is a convenient provisional size, **not an age-based recommendation**. The mask's eye openings, cheek clearance, band tension, spire length/stiffness, and support balance remain to be fitted independently.

For an initial uniform paper trial, print all cutting sheets at the same percentage. If a measured headband path is H mm, H/540 × 100% is only a starting scale, not proof of facial fit. A 100 mm scale ruler then prints at 100 × that factor mm; do not demand 100 mm after deliberately scaling. At the supplied 100% print setting, it must measure 100 mm. Record changes on the paper masters. Changing eye spacing requires moving/enlarging openings, not blindly applying circumference scale. For enlargement use Poster/Tile Scale printing or resize the SVG canvas and artwork together; ordinary scaling on a fixed sheet may clip parts near the margins. Keep paper-fitting mandatory before foam.

## Drawing set

Create four cutting-sheet SVG masters under `patterns/helmet/`, each in millimeters on a Letter-sized canvas. All pieces fit wholly on their sheet and inside the A4 printable area; **no piece spans pages**, so unnecessary page tiling/taping is avoided. Make five-page Letter and A4 PDF packs containing the four cutting sheets plus an assembly key. In the A4 pack, change paper dimensions without scaling artwork. Include an assembled preview PNG for quick visual review.

| Sheet | IDs / contents | Cut quantities for one helmet |
|---|---|---|
| 01 | A eye/brow frame; E brow ridge; G forehead accent; K forehead support patch; L temple support tab | A ×1; E ×2 mirrored; G ×1; K ×1; L ×2 |
| 02 | B central split face ridge; C main cheek; C2 cheek inset | B ×1; C ×2 mirrored; C2 ×2 mirrored |
| 03 | D swept temple plate; S1 central front spire; S2 central rear spire | D ×2 mirrored; S1 ×1; S2 ×1 |
| 04 | S3 tall side spire; S4 short forward spire; H paper support strip | S3 ×2 mirrored; S4 ×2 mirrored; H ×6 for the paper support |
| 05 | Assembly key: front illustration and crown positions | Reference only; **not a cutting sheet or an orthographic assembly projection** |

One template is provided per distinct shape. For mirrored pairs, trace onto spare paper and flip the template for the second piece; print selected pages again if preferred. Do not turn a drawn front silhouette into a cutting pattern: the flat components and assembled illustration are deliberately separate.

Solid black lines are cuts, including eye and breathing openings. Dashed blue lines are placement/bond-zone references, not cuts. Dash-dot green lines indicate a shallow paper forming fold, not a foam knife cut. Gray labeled diamonds are matching placement anchors; alignment remains adjustable during fitting. Use line styles and labels as well as colors for grayscale printing. Show ID, quantity, mirroring, and eventual foam thickness on every shape's sheet. Every PDF page carries **PAPER FIT ONLY**, the nominal size, print instruction, and a 100 mm physical scale ruler.

## Paper support and component assembly

Use light cardstock/paper, a ruler, scissors, and tape. Adult supervision; cover sharp paper edges, and do not put pins/staples near the wearer.

1. Cut six copies of H, a 25 × 165 mm paper strip. Four strips make the band: join three seams with 20 mm overlap, giving 600 mm developed length; a separate 60 mm adjustable rear overlap gives a 540 mm loop. Two further strips joined with 20 mm overlap give a 310 mm over-head strap. Its provisional 20 mm attachment at each end leaves a 270 mm over-head span. Adjust on the actual child rather than forcing these dimensions. Paper tape closures should open easily.
2. Fit band and side-to-side over-head strap loosely. The child must be able to lift them off and reach the rear overlap. This strap locates band height; it does not establish stability against forward mask weight.
3. Curve A gently around the face and place B over its center using the A/B anchor. B is narrow at eye level to avoid covering A's eye openings, with a split lower outline and a separate breathing slot. Tape B's upper A/B area only; leave its lower portion free. The short forming guide below eye level allows a gentle forward angle away from the nose/mouth. Fold K to establish an adjustable forehead stand-off instead of laying the facade directly against the forehead. These paper adjustments do not guarantee clearance: fit the actual child, and recheck tipping when the gap changes. Enlarge or shorten anything that obstructs breathing or sight.
4. Attach C to each side at the A/C anchor; wrap it toward the side, rather than treating its entire flat width as added frontal width. Attach D behind the cheek/frame at the A/D anchor. Where plates overlap, temporarily tape a small contact area on the outside. These are adjustable lap placements, not precision edge-to-edge seams. Keep the back open.
5. Fold K along its center guide: center its face half behind A in the marked forehead zone, and tape its band half to the front band, bending as needed to establish clearance. Rotate each L a quarter-turn so a 25 × 20 mm half matches A's 20 × 25 mm blue side box; tape that half directly behind A and fold the other toward the band at the temple. Attach L before D, and position D behind the sides without covering L's fold or free band half; D is decoration, not the only support attachment. Use broad outside tape contact areas. Forehead **and** temple attachment are required; do not hang the face from two temple tabs alone. Add small soft pads only if necessary and keep sight openings clear.
6. Add E and G only after basic fitting. Place C2 using its two C/C2 anchors, lining up the corresponding diamonds on C. These are decorative overlay pieces; they must not cover the eyes, breathing slot, or removal path. Overlays can be omitted if too bulky.
7. Gently form S1–S4 along their center guides into shallow open-backed V sections; a roughly 120° interior angle is an aesthetic paper starting point, not a calibrated requirement. Roots are 25 mm long. Fold/curve the root to suit its crown position, then tape it to the support with the root allowance overlapping the band. **Do not add the 25 mm root again** to the cut outline. The six positions are S1 front center, S4 left/right forward, S3 left/right sides, S2 rear center. Points can lean outward slightly, but check overhead clearance and balance.
8. Add points incrementally, testing whether the paper facade tips or slips toward the eyes. All principal spires have visibly blunted ends, not mathematical needle tips. Paper may still have sharp corners on crests, cheeks, or other edges; tape or round them further for fitting. If unstable, stop and revise the support rather than tightening painfully or adding a chin strap.

Assembly illustrations communicate layers and approximate placement, **not verified 3D joint geometry**. The rear center root must mount beside/above the reachable rear band overlap, not tape across it; the release/removal path stays clear. No closed rear shell is required.

## Eventual EVA construction, after fitting

Tentative materials: 4 mm EVA for A–D and spires, 2 mm for E/G/C2, soft 4–6 mm EVA for support patches, approximately 25 mm soft webbing for the final support. Those are starting choices, not stiffness/comfort specifications. Thin 4 mm spires may fold: shorten/widen them before considering heavier foam. No wire, rods, dowels, resin, or hardened coating.

The paper H strips are **support fitting aids**, not instructions to make the final wearable band out of cardstock or long stiff EVA strips. Transfer the accepted support lengths to adjustable webbing, sew webbing joints, and bond foam through broad manufacturer-compatible scrap-tested patches. Rear hook-and-loop must be reachable without catching hair. No chin/neck strap.

Paper crease lines are forming guides. Foam can be heat-shaped off the child to a shallow ridge; do not cut through the center line. Do not treat paper folds as a tested EVA development. Round all exposed nose, cheek, and spire edges, and test the first cured foam brow/support before adding cheeks and points. Repeat fitting after every substantial addition. No hot glue or heat shaping on the wearer. An adult handles cutting, heat, solvent adhesives, and painting with manufacturer ventilation/PPE/fire precautions; keep the child away from the work area.

Finish only after physical fitting passes. Use flexible compatible coatings, black/dark gunmetal and restrained silver edge highlights, not a hard resin shell. Fully cure/ventilate adhesives and coatings to their instructions before wear; odor absence is not a cure test.

## Acceptance and verification

Document checks must verify:

- All four masters have the intended physical millimeter sizes and quantity labels, including all six principal spires via the cut list.
- Black cutting geometry is wholly within each page, with no component clipped or split, and IDs/placement marks remain legible.
- Final Letter and A4 PDF pages have the correct paper dimensions and reproduce actual cutting-path segments and placement/fold references at the same physical scale. Checking only the separate ruler is insufficient.
- Every page has its 100 mm ruler and provisional warning. Deliberately distort a copied cutting path while leaving the ruler unchanged; the physical-geometry comparison must fail before trusting it.
- Front illustration and crown-position diagram agree with the cut IDs/counts, with illustration explicitly labeled not to cut. Render and inspect pages visually; quantitative checks do not prove a usable drawing.

Physical checks remain unverified until the child tries the paper and then the foam version. Begin stationary, then supervised walking on a clear flat floor; no running/stair trial. Stop immediately for discomfort, dizziness, breathing difficulty, blocked vision, or instability. Check floor/peripheral sight, speech/breathing, head turns/downward look, glasses clearance if relevant, forehead/nose/ear pressure, independent removal, crown/body/door clearance, and alignment. The whole costume can change shoulder clearance. Later foam wear trials must separately check cured joint retention, finished weight/balance, flex/softness, and heat buildup; a brief indoor trial does not establish long-event comfort. This is not protective headgear or a safety certification.

## Independent drawing review

Opus 5.5 reviewed this revision's exact text and rendered drawings, then a focused correction for temple-tab placement, forehead-accent eye clearance, and adjustable forehead/nose stand-off. The follow-up returned **“No supported substantive findings.”** This does not establish physical fit. Parent checks of the actual final PDF geometry, the failing scale-corruption probe, and finding dispositions are recorded in the [paper-template review](file:///home/kurtt/sauron-cosplay/docs/superpowers/reviews/2026-10-03-sauron-helmet-paper-template-review.md).

`/home/kurtt/sauron-cosplay/docs/superpowers/reviews/2026-10-03-sauron-helmet-paper-template-review.md`

## Approval boundary and progress

The user approved provisional paper sizing and the proposed more movie-like direction. These drawings remain **design-review/paper-fit artifacts**, not authorization to claim a fitted helmet or go straight to foam construction. Review the drawings and paper fit before producing a measured final pattern or implementing a parametric generator. No Git initialization is required; this folder has no Git metadata.

- [x] Confirm provisional rather than measured sizing with the user.
- [x] Inspect production-helmet photographs and define six principal spire positions.
- [x] Specify original flat pieces, paper support arithmetic, print format, and fit limits.
- [x] Create provisional full-size drawing masters and PDF packs.
- [x] Check exported physical geometry and visually inspect the sheets.
- [x] Independently review this exact design/drawing revision.
- [ ] User reviews drawings and paper fit; record dimensions and corrections.
- [ ] Create a measured final pattern and build/wear-test foam after fitting.

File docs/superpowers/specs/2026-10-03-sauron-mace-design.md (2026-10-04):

# Child-sized Sauron mace: blade patterns and adapters

Status: approved by the user on 2026-10-03; implementation plan written, execution-method selection and tool installation pending.

## Purpose and scope

Create editable cutting patterns and printable adapters for an approximately three-quarter-scale Sauron cosplay mace carried by a 4′8″ nine-year-old. Preserve the approved construction: approximately 35 inches overall, nominal ¾-inch PVC, six EVA-foam blades, two small printed adapters, and permanent glued assembly. Keep exposed tips soft and weight low, especially at the head.

Deliver the blade outline, adapter, fit coupon, assembly preview, print-ready patterns, and concise fabrication instructions. This is a carrying/photo prop, not a striking toy. Film-exact engraving, a complete printed handle, armor, removable joints, and load-bearing/impact certification are outside this first build.

## Selected modeling approach

Use **one parametric OpenSCAD file** as the canonical geometric source. It supplies a 2D blade outline and 3D adapter/preview geometry. A small export script invokes OpenSCAD and uses the already-installed CairoSVG package to make printable PDF pages from the exported SVG; it must not contain a second copy of the blade coordinates or mounting dimensions.

A `metadata` mode emits tagged, machine-readable `echo()` data with derived blade bounds, station centers, mounting-band extents, dimensions, and the model-to-SVG axis convention (radial X maps to SVG X; positive axial distance maps to negative SVG Y). `export.py` honors that transform and the native SVG `viewBox`, then adds dashed reference marks, labels, and the calibration bar in the same coordinate space. It must not recalculate station positions from independent constants or fit the outline and marks to separate bounding boxes. This resolves OpenSCAD's unstyled SVG output without duplicating geometric definitions.

Alternatives considered:

- Hand-authored SVG plus separate OpenSCAD adapters: fewer export steps, but duplicates the mounting dimensions and risks a pattern/adapter mismatch.
- CadQuery or another Python solid-modeling stack: capable, but adds a substantial dependency for two simple slotted rings.

OpenSCAD gives native SVG and STL exports and an interactive preview with little project infrastructure. No framework or package scaffolding is needed.

## Initial dimensions and coordinate contract

All CAD dimensions are millimeters. Nominal values are starting points, not verified printer fits.

| Parameter | Initial value / meaning |
|---|---|
| Overall prop length | 889 mm (35 inches), including foam pommel and tip |
| Blade axial length | 295.275 mm, rounded only for display |
| Nominal head diameter | 130 mm across opposed blade radial centerlines; an adjustable project choice, not a verified replica dimension. Foam thickness slightly increases the circumscribed envelope. |
| Pipe OD | 26.67 mm; replace with actual measured OD |
| Pipe bore clearance | +0.50 mm on **diameter**, initially |
| Foam thickness | 10 mm; replace with measured foam thickness |
| Foam slot clearance | +0.50 mm on **total width**, initially |
| Blade count | Six; centers spaced 60 degrees |
| Adapter outside diameter | 60 mm |
| Adapter axial height | 16 mm |
| Slot inner radial coordinate | 18.5 mm from the pipe axis |
| Slot outer opening | Through the adapter's outer perimeter, nominal radius 30 mm |
| Adapter station centers | 45 mm and 225 mm from the blade's lower end |
| Minimum core wall | At least 3 mm from bore surface to any slot |
| Foam tip extension past PVC end | 35 mm |
| Foam beyond PVC at pommel end | 15 mm |
| Shaft foam-covering allowance | 3 mm radially, outside adapter/cap seating areas |
| Blade-to-cover/cap clearance | At least 0.5 mm radially |
| Top foam cap | 36 mm maximum OD; 15 mm sleeve overlap plus 35 mm soft extension; blunt tip radius 3 mm |
| Foam pommel cap | 40 mm OD and 40 mm axial length; 25 mm sleeve overlap plus 15 mm solid foam beyond PVC |

The blade's 2D coordinates are **radial distance from the pipe axis** and **axial distance from the blade's lower end**. The 3D adapter's bore runs along the assembly axis. Preview extrusion of each blade is centered on its radial plane, so a 10 mm blade fits a 10.5 mm slot.

For the default length layout: blade lower end is at 593.725 mm from the pommel extremity, blade tip at 889 mm, PVC starts at 15 mm and ends at 854 mm. The corresponding provisional PVC cut length is **839 mm**, not 889 mm. Dry-fit first; optional pommel decoration must stay inside the chosen overall envelope or explicitly update it.

Changing blade length rescales its axial features, including the two mounting stations. Changing pipe OD or foam thickness does **not** uniformly rescale the prop. Derived geometry must preserve the mounting contract or reject an incompatible configuration clearly.

## Blade and adapter interface

Create a recognizable, simplified Sauron blade silhouette using the United Cutlery drawing linked in `SOURCES.md`. It is an original approximation, not a precision tracing of the low-resolution reference. Prioritize the elongated profile, swept outer lobes, and relieved inner edge over engraving. Use six identical blades; do not cut sharp rigid reinforcements into their outer points.

At each adapter station, the inner blade edge includes a **straight mounting land at radial coordinate 18.5 mm**. Each land spans the full adapter height plus 3 mm at either end: 22 mm total. Throughout that band, the blade extends radially beyond the adapter perimeter. Neither an inner-edge relief nor an outer notch may cut into this required material. Show the bands and adapter-center marks on the printed pattern as reference marks, **not additional cut lines**.

Keep the **entire blade outline at or outside the slot's inner radial coordinate**, not just the mounting lands. Inner-edge reliefs move away from the axis; no blade tip curls inward. The default minimum radius is therefore 18.5 mm and the maximum is 65 mm, giving a 46.5 mm radial outline width. Also require clearance from the covered pipe and the top foam-cap envelope along their full axial spans. Reject pipe, covering, cap, or blade configurations that overlap or leave less than the stated 0.5 mm clearance; a radial insertion path from outside must remain clear except for intended contact inside the slots.

The same adapter STL is printed twice. It is a cylindrical ring with a continuous bore wall and six straight radial slots open to the outside, extending through the adapter height. The foam roots slide inward into these slots and stop at the inner radial coordinate. No dovetails, clips, fasteners, or inaccessible internal cavities are needed.

Dry-fit both rings on the PVC, aligned at the same angular orientation and correct station spacing. Insert all six blades radially before permanent gluing. Cover visible plastic after fitting; foam covering must not occupy the bore or blade slots and invalidate their measured fit.

Print rings with the bore axis vertical, flat on the bed. Through-slots and the vertical bore should require no supports. Use a thin, approximately 5 mm-high version of the same ring as the fit coupon; it exercises both the real bore and the real six-slot geometry.

## Foam end-cap envelopes

Represent both end caps in the OpenSCAD assembly and clearance checks, **not as printed parts**. Their dimensions are provisional project choices, not verified impact-protection requirements. Make them from stacked EVA and hand-shape them; exact decorative cap patterns are unnecessary for this first build.

- **Top cap:** a 36 mm-OD cylindrical foam sleeve overlaps the bare pipe by 15 mm, ending at the PVC endpoint. Above it, 35 mm of solid foam tapers to a blunt 3 mm-radius tip. The sleeve's nominal cavity uses the same 27.17 mm fit diameter, giving approximately 4.4 mm of side foam. In blade-local coordinates the cap occupies 245.275–295.275 mm; only its first 15 mm has a pipe cavity. Its maximum radius is 18 mm, leaving 0.5 mm to the blade roots. The cap starts 9.275 mm above the upper mounting band's end, so it does not intrude into the adapter or land. Changed configurations must preserve this separation or fail explicitly.
- **Pommel cap:** a simple 40 mm-OD, 40 mm-long foam envelope occupies global axial coordinates 0–40 mm. Its cavity opens at the upper end and stops at 15 mm, so the PVC begins at 15 mm and the lowest 15 mm remains solid foam. It is well below the blade region. Round its outside during finishing without extending past the specified axial extremity.

Glue compatible foam caps to the bare pipe only after a scrap adhesion test. Cut the actual foam cavities to suit the measured pipe; modeled clearances do not establish adhesion or cushioning performance. Shaft wrapping stops before the cap sleeves and adapter bores; do not layer wrapping under a part designed to fit bare PVC. Cover the adapters' exposed surfaces after blade seating, without blocking slots. Verify cap retention, no exposed hard endpoints, and carrying comfort in the physical mockup. If adequate padding requires larger envelopes, update the model and recheck blade clearance rather than squeezing an oversized cap into the existing head.

## Files and outputs

- `mace.scad`: source model with selectable `blade_2d`, `metadata`, `adapter`, `fit_coupon`, and `assembly` modes, including parameterized foam-cap envelopes in the assembly; assembly is the normal preview, never the fabrication STL.
- `export.py`: a small export entry point; uses an available OpenSCAD executable and CairoSVG. Missing tools or failed renders are explicit errors, not placeholder output.
- `patterns/`: one full-size SVG and tiled printable SVG/PDF pages for **A4 and US Letter**. Individual numbered PDF pages are acceptable; no PDF-merging dependency is necessary.
- `prints/`: separate adapter and fit-coupon STLs, only after successful OpenSCAD rendering and checks.
- `README.md`: dimensions, adjustable parameters, regeneration command, print settings, fit-check sequence, provisional pipe cut layout, assembly, and practical limitations.
- `SOURCES.md`: URLs, verified dimensions, indexed-only leads, and the distinction between sourced facts and our choices.
- One small executable check for the geometry and export contract; use existing tools or standard-library checks, not a new test framework.

Tile at actual physical scale with at least 10 mm printer margins and 10 mm overlap. Pages need format/page identification, alignment marks, clear cut versus mounting-reference line styles, and a **100 mm calibration bar** on a page where it fits. Numbered pages must use a common coordinate origin so taping them together does not shift the blade outline. Print at 100% / Actual Size; verify the bar with a ruler before cutting foam. Parameter changes that require more pages must produce more pages, not clip or shrink the pattern.

## Verification and physical acceptance

Digital checks must establish:

1. Default blade bounds are axial 0–295.275 mm and radial 18.5–65 mm; the outline is a valid, non-self-intersecting single region. The full foam volume and its radial insertion path clear the pipe, wrapping, and cap envelopes; adjacent blades do not intersect. Ignore only the intended seated blade/slot contacts.
2. All six slot positions and both blade mounting lands agree in the assembly coordinate system. Lands encompass the full station height, including the stated allowance. Exported metadata and reference marks use these same model coordinates.
3. Default bore is 27.17 mm and default slot width is 10.5 mm; at least 3 mm of core wall remains. Covered-pipe and cap clearance is at least 0.5 mm; the top cap does not overlap either adapter or mounting band. A changed pipe OD, foam thickness, covering, or cap envelope either works coherently or fails explicitly. Mounting lands retain their required absolute height when blade length changes; reject a blade too short to accommodate the lands and caps.
4. The two fabrication STL modes render as nonempty single connected solids with a through-bore and open slots; assembly-only geometry, including foam caps, cannot enter their files.
5. Tiled page dimensions, overlap, complete outline coverage, and the 100 mm bar are preserved in SVG and PDF exports. A4 and Letter dimensions are not interchangeable. **Measure the exported blade path itself**, excluding reference marks: default physical bounding-box size must be 295.275 mm axial by 46.5 mm radial, within 0.1 mm. Measure this in final SVG physical units and final PDF page/path coordinates; for tiles, reconstruct bounds using the recorded common-origin offsets. Compare against model-derived bounds for nondefault configurations. A correctly sized script-drawn bar alone does not verify outline scale.
6. The check demonstrably fails on an intentionally invalid configuration or broken expectation, then passes after restoration. Include a deliberate outline-unit/scale corruption with the calibration bar unchanged, proving the exported-outline measurement binds.

Physical acceptance remains separate: print the coupon, check the actual PVC and foam, assemble one blade temporarily, check flop and adhesive compatibility, then let the child try carrying the mockup. Weigh the finished prop. Adjust clearance and foam thickness before committing to all six blades. Neither a rendered STL nor a passing geometric check proves carrying comfort or joint strength.

Printed adapters are not PVC fittings: do not assume plumbing PVC solvent cement bonds PLA or PETG. Select adhesive by its manufacturer's material compatibility, test on scraps, and have an adult handle cutting, printing, adhesives, heat, and finishing. Pad/cap both pipe ends, maintain the soft tip extension, cover visible hard edges, and check the venue's rigid-core prop rules.

## Current environment and approval boundary

The project folder began empty and is **not a Git repository**, so no design commit is possible without separately initializing one. Do not initialize Git merely to satisfy a workflow checkbox.

Python, Pillow, and CairoSVG are available; **OpenSCAD is not installed**. Source creation does not justify claiming STL verification. The implementation plan must establish how to run OpenSCAD (approved installation or an operator-provided executable) before fabrication exports can be accepted.

### Review disposition

Opus 5.5's first completed text-only review covered spec SHA256 `1d7ebf4087739624462369d118f5dede5788ff52c5037f5f0b580f015c449b50`. The parent verified the dimensional arithmetic and accepted the four practical gaps:

1. **Inner clearance:** bound the complete profile outside the slot roots and explicitly check pipe, covering, cap, and insertion-path clearance.
2. **Unspecified end caps:** define adjustable foam-only envelopes and their seating/padding layout. The earlier spec already required padded endpoints; this clarifies them without adding printed cap parts. These are not proven safety dimensions.
3. **Reference export:** explicitly use OpenSCAD-derived metadata for styled reference marks. Distinct styling was possible, but its single-source mechanism had not been specified.
4. **Export scale:** measure the actual final blade path, not merely the separate calibration bar; include a scale-corruption negative check. The default 46.5 mm width follows the newly explicit radial bounds, not a replica measurement.

Numerical check: bore 27.17 mm; bore-to-slot wall 4.915 mm; top cap sleeve wall approximately 4.415 mm; cap-to-blade radial clearance 0.5 mm; cap begins 9.275 mm beyond the upper land. CAD rendering and physical suitability remain unverified.

The focused follow-up reviewed the corrected contract at spec SHA256 `c048bce92aa7e4a3f95775044a6f5e4299d1ce62e22a682293e7fb55ad193551` and returned **“No supported substantive findings.”** Run `0fdb18da-ab39-4821-a7e7-fe98632839d7` completed using verified `claude-opus-5-5`, requested medium effort, read-only Plan Mode with no tools. The review was of the supplied corrected-spec packet, not executable CAD or physical fit. Remaining cap tolerance, retention, and tooling uncertainties are covered by the implementation and mockup checks above. This record and the checklist update are administrative changes after that reviewed version; the geometric contract is unchanged. Stop the refinement pass and request user approval.

### Process checklist

- [x] Capture approved physical intent and permanent assembly decision.
- [x] Inspect the project folder, tools, and dimensional sources.
- [x] Compare modeling approaches and write the geometric interface contract.
- [x] Record sources and distinguish project choices from verified dimensions.
- [x] Self-review dimensions, fit-clearance definitions, coordinate agreement, and approval boundaries.
- [x] Receive the first completed independent spec review and verify/dispose its findings.
- [x] Recheck the substantive corrections with Opus 5.5 at medium effort: no supported substantive findings.
- [x] Obtain user approval of this written spec on 2026-10-03.
- [x] Write and self-review `docs/superpowers/plans/2026-10-03-sauron-mace-implementation.md`.
- [ ] Obtain user review of the plan and execution-method selection.
- [ ] Implement, verify exports, and document physical checks.

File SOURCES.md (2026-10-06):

# Sauron cosplay mace — sources

Research recorded: 2026-10-03. This is a lightweight carrying/photo prop for a 4′8″ nine-year-old, not a striking toy. The intended build is approximately 35 inches overall, with a nominal ¾-inch PVC core, six EVA-foam blades, and a split tapered printed blade holder (the original two-ring adapters remain an alternative).

## Dimensional and visual references

### United Cutlery — The Mace of Sauron and the One Ring, UC3034

- URL: https://www.unitedcutlery.com/ProductDetail.aspx?c=&itemno=UC3034
- Evidence: manufacturer's product description, fetched directly.
- Published dimensions: **46⅜ inches overall; 15½-inch blades**.
- At 75%: **883.44 mm / 34.781 inches overall; 295.275 mm / 11.625-inch blades**.
- Use: principal length reference. The proposed build rounds the overall length to **889 mm / 35 inches**, but retains approximately **295.3 mm** blades.
- Limitation: this describes a steel-reinforced polyresin display replica, not a child-safe foam construction. Its materials are not our build recipe.

### United Cutlery drawing published by TheOneRing.net

- Article: https://www.theonering.net/torwp/2015/03/02/97253-beyond-middle-earth-united-cutlery-brings-the-hobbit-and-lord-of-the-rings-weapons-to-life/
- Drawing: http://www-images.theonering.org/torwp/wp-content/uploads/2015/02/PD4646-Mace-of-Sauron-Drawing_s.jpg
- Evidence: article fetched directly; the drawing was visually inspected during the initial research.
- Use: six-blade arrangement, blade silhouette, shaft sections, and decorative motifs.
- Limitation: the published image is only 864 × 382 pixels. Small annotations are difficult to read. The earlier approximately 45⅞-inch interpretation of the drawing differs slightly from the production replica specification above; use the manufacturer's explicit dimensions for lengths.
- Any new cutting pattern will be an **approximation inspired by this drawing**, not a precision film-prop tracing. Do not treat a chosen head width or mounting detail as a sourced dimension.

## Foam construction and existing patterns

### Storm the Castle / Will Kalif — Make Sauron's Mace

- Tutorial, part 1: https://stormthecastle.com/how-to-make-a/saurons-mace.htm
- Tutorial, part 2: https://stormthecastle.com/how-to-make-a/saurons-mace2.htm
- Free three-page pattern PDF: https://stormthecastle.com/how-to-make-a/saurons-mace/saurons-mace-pdf.pdf
- Evidence: both tutorial pages fetched directly; the PDF was successfully fetched and identified as three pages. Its cutting geometry has not been measured.
- Published construction: approximately 24-inch broomstick, six foam-board blades, cardboard fittings, and a lightweight pommel.
- Use: accessible construction reference and an existing simplified blade pattern.
- Limitations: foam board is not EVA; this is a simplified craft interpretation. Its template is not established as a full-size replica pattern. **Do not assume printing it at 75% produces our intended blade size.**

### Instructables — Sauron's Mace From Lord of the Rings

- URL: https://www.instructables.com/Saurons-Mace-From-Lord-of-the-Rings-2/
- Evidence: found in search; direct fetch failed because the page appears JavaScript-rendered.
- Use: additional construction lead. Not an independently verified dimensional reference.

## Existing printable models

### MakerWorld — Sauron's Mace, model 477771

- URL: https://makerworld.com/en/models/477771-sauron-s-mace
- Alternative listing: https://www.thingiverse.com/thing:6652328
- Evidence: indexed descriptions; MakerWorld direct fetch was blocked by HTTP 403. Downloadable CAD/mesh files and licensing have **not** been inspected.
- Indexed description: V2 accommodates nominal **½-inch PVC** throughout the model; the complete printed mace is approximately 46 inches long. The listing warns that a fully printed version can weigh upwards of 2 kg.
- Use: assembly reference and possible inspiration for shaft decoration.
- Limitations: not a ready-made EVA adapter kit, and not designed for our ¾-inch pipe. Uniformly scaling the model also changes its bore. Verify the version, geometry, and license before reuse or redistribution.

### Printables — Sauron's Mace by Nikoraasu

- URL: https://www.printables.com/model/588352-saurons-mace
- Evidence: indexed description; direct fetch was blocked by HTTP 403. Model files and licensing have **not** been inspected.
- Indexed description: **16 mm central bore** for a reinforcing stick, plus two 5 mm holes for additional anti-rotation rods.
- Use: alternative shape/assembly reference.
- Limitation: a 16 mm bore does not accommodate our selected 26.67 mm outside-diameter pipe. Do not adopt the extra rods for this child-oriented foam prop by default.

## Pipe dimensions

### Wavin — PVC Pipe Schedule 40, ASTM D1785

- Datasheet: https://wavin.us/hubfs/Product%20Literature/PVC%20Schedule%2040/SS%20-%20PVC%20Sch%2040.pdf
- Evidence: three-page manufacturer PDF fetched and its extracted text inspected; see Table 1.
- Nominal ¾-inch pipe: **1.050 inches / 26.67 mm OD**, **0.113 inches / 2.87 mm wall**.
- Nominal ½-inch pipe: **0.840 inches / 21.34 mm OD**, **0.109 inches / 2.77 mm wall**.
- Use: initial adapter bore sizing. These figures describe US nominal Schedule 40 plumbing PVC; other pipe systems may differ.
- **Measure the actual purchased pipe**, then print a fit coupon. Nominal size is not outside diameter; printer and pipe tolerances are not established by this datasheet.
- Earlier pipe-weight figures were rough estimates, not measured build weights or values verified in this datasheet. Weigh the actual core and finished assembly.

## Project choices, not sourced facts

The following are our design decisions rather than claims from the references:

- 35-inch / 889 mm overall target and permanent glued assembly.
- Nominal ¾-inch PVC core; nominal 10 mm EVA as the initial blade material.
- Blade design D ("spiked"): an adaptation of the drawing's blade side view (sturdy body, spear tip, round bite, barbed opening, hooked outer spike, crescent base horn), fitted to the existing ~3/4-scale 295.275 × 46.5 mm envelope and mounting bands. Feature sizes are project choices, not measured drawing dimensions.
- A hexagonal spindle holder following the drawing's 380 mm core silhouette (base collar, waist, single swell, long taper), with blade grooves at its six vertices only where the blades meet it, and an integrated pointed printed crown (ball tip removed at the user's request), recessed 12 mm below the EVA blade tips. Total height approximately 246 mm, split perpendicular to the handle axis into two approximately 123 mm sections for an A1 mini. Proportions, clearances and the transverse split are project choices, not measured drawing dimensions. The existing blade shape, 180 mm mounting-station spacing and PVC layout are retained; no second 75% scaling is applied.
- A small fit-test print and optional original two-ring alternative; adapter OD 60 mm, height 16 mm, slot roots at radius 18.5 mm.
- Nominal head span 130 mm across opposed blade centerlines; the cutting outline has initial radial bounds 18.5–65 mm.
- Independently adjustable pipe clearance, foam-slot clearance, blade length, and head width.
- Soft EVA blades and pommel, with a rounded hard crown intentionally recessed inside the blades as requested by the user. This does not establish impact protection: the blades can bend or tear. The pommel is 40 mm OD × 40 mm long, including 15 mm solid foam beyond the PVC. For the optional two-ring build only, the legacy foam top cap has 36 mm maximum OD, 15 mm sleeve overlap and 35 mm soft extension. These are geometric starting choices, not validated protection dimensions.

Digital fit checks cannot establish adhesive strength, foam stiffness, carrying comfort, or suitability under an event's prop rules. Validate these with a physical coupon and a one-blade mockup before cutting all six blades or gluing the final assembly.

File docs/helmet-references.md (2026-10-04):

# Sauron helmet — references for original printable EVA templates

Research: 2026-10-03. Requested direction: a middle ground between the Woodland Elf craft version and highly detailed replicas, with a more movie-like silhouette and explicit printable patterns for all crown spikes. Wearer remains the same nine-year-old. This is reference research, not fitted geometry or a fabrication approval.

## Primary visual reference: actual production helmet

- [Propstore: Sauron's (Sala Baker) helmet](https://propstore.com/product/lord-of-the-rings-the-the-fellowship-of-the-ring-2001/saurons-sala-baker-helmet/)
- [360-degree viewer](https://content.propstore.com/auction/emlaus25-2/360s/307783/307783.html)
- [Front photograph](https://images.propstore.com/080a39c1e54f25cc59a32e7bb2f23181.jpeg)
- [Front three-quarter photograph](https://images.propstore.com/8a27456b61364de9f9a7b44b470e8e04.jpeg)
- [Side photograph](https://images.propstore.com/f1c0cc21d82faf4e4735642e4953398e.jpeg)
- [Rear three-quarter photograph](https://images.propstore.com/c0b61ab8c055ab82a490afb7a06b6a25.jpeg)
- [Rear photograph](https://images.propstore.com/c06ad211876d3d107fbeec762f6f044a.jpeg)

Evidence: the listing was fetched and the five linked gallery photographs visually inspected. The viewer configuration was fetched, but its complete rotation was not inspected. The publisher identifies the item as a Weta-made original used as reference for licensed replicas. It describes urethane construction, rubber details, leather lining, and black/silver decoration with a blue sheen. Those materials are not our child costume recipe. Published bounding dimensions are not usable child fitting dimensions or flat foam developments.

Observed features worth retaining:

- Six prominent crown spires: a tall swept side pair, a shorter forward pair, one central front spire, and one central rear spire. This replaces the earlier arbitrary five-point proposal if the revised design is approved. Small notches/points along plate edges are separate decorative features.
- Narrow central face ridge, long split lower face, angular brow, and layered swept cheek/temple plates; not just a wide flat mask with a crown attached.
- Spires have faceted/tapered depth rather than looking like rectangular strips.
- Edge ridges and overlapping panels do much of the visual work; fine etched ornament is secondary.

These are visual interpretations from perspective images, not orthographic tracings or exact measured geometry. The assembled costume should be proportioned to the child, with larger practical sight openings and softer, shorter points as needed.

## Secondary reference: licensed replica

- [United Cutlery half-scale helm, UC3521](https://www.unitedcutlery.com/ProductDetail.aspx?cat=LR&itemno=UC3521)

Manufacturer text was fetched. It describes a 15½-inch-tall polyresin display reproduction based on an original prop casting. Use only as supplementary visual context; do not enlarge a half-scale display object's dimensions to determine a child's head fit.

## Construction/detail reference, not our material recipe

- [Blind Squirrel Props: Helm of Sauron](https://www.blindsquirrelprops.com/helm-of-sauron/)

The walkthrough text was fetched and its final side-detail photograph inspected. Its layered sculpting and ridge placement are useful visual aids. Its resin/styrene spikes, dowels, epoxy work, and eye-covering insert are **not** proposed for this child build. The author's replica-size and wearing-comfort observations concern their own build, not validated measurements for ours.

## Intended next deliverable

Original EVA cutting drawings, including all six major spike positions, plus placement/assembly diagrams. A useful compromise is layered face panels and simple shallow folded/faceted foam spires, without reproducing the intricate engraving or a closed heavy shell. Exact flat developments, joint allowances, support layout, and dimensions still need a design revision and paper fitting; a projected assembly view is not a cutting template.

For practical home printing: US Letter and A4 tiled PDFs at Actual Size, full-size editable SVGs, 100 mm scale bars, page overlap/alignment marks, and component IDs, quantities, thicknesses, mirroring and fold/bond marks. Full-size must mean explicitly dimensioned geometry, not a claim of fitted sizing without measurements. If a provisional size is authorized, label every sheet as a paper-fit prototype.

Link to reference photographs and existing third-party patterns rather than redistributing them. Draw original cutting geometry. No rights to republish the source images or source pattern have been established.

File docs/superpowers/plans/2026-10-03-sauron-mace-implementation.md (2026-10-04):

# Sauron Mace Patterns and Adapters Implementation Plan

> **For agentic workers:** REQUIRED SUB-SKILL: Use superpowers:subagent-driven-development (recommended) or superpowers:executing-plans to implement this plan task-by-task. Steps use checkbox (`- [ ]`) syntax for tracking.

**Goal:** Produce editable OpenSCAD geometry, verified foam-blade cutting patterns, and two small printable adapter designs for the approved child-sized Sauron prop.

**Architecture:** `mace.scad` owns every geometric dimension, blade point, and mounting station. `export.py` invokes OpenSCAD, styles and tiles its actual SVG, renders PDFs with existing CairoSVG, and verifies the fabrication outputs. One standard-library test file exercises the same render and verification functions used by the real export command.

**Tech Stack:** OpenSCAD, Python 3, existing CairoSVG, Python's `unittest`/XML/JSON/subprocess libraries, and Poppler's PDF-to-SVG conversion. No web service, application framework, CAD Python stack, or custom PDF parser.

**Spec:** `docs/superpowers/specs/2026-10-03-sauron-mace-design.md`, approved by the user on 2026-10-03 after the Opus 5.5 follow-up returned no supported substantive findings.

## Global Constraints

- Approximately 35 inches overall: **889 mm**, including foam ends; provisional PVC length **839 mm**, not 889 mm.
- Six identical blades; centers spaced **60 degrees**. Default axial bounds **0–295.275 mm**, radial bounds **18.5–65 mm**; outline width **46.5 mm**.
- Nominal ¾-inch US Schedule 40 PVC: initial measured-OD input **26.67 mm**. Bore clearance **+0.50 mm on diameter**; default bore **27.17 mm**.
- Initial foam **10 mm**; slot clearance **+0.50 mm on total width**; default slot **10.5 mm**.
- Adapter OD **60 mm**, height **16 mm**, slot floor radius **18.5 mm**; stations **45 mm** and **225 mm** from the blade base. Print the same adapter twice.
- Mounting lands cover adapter height plus **3 mm at either end**, **22 mm** total. Minimum bore-to-slot wall **3 mm**; cover/cap clearance at least **0.5 mm**.
- Top foam cap: maximum OD **36 mm**, sleeve overlap **15 mm**, soft extension **35 mm**, blunt tip radius **3 mm**. Pommel: OD **40 mm**, length **40 mm**, including **15 mm** solid foam beyond the PVC.
- Caps are assembly/check envelopes, **not printed parts**. Only adapter and approximately **5 mm-high** fit-coupon geometry belongs in fabrication STLs.
- Metadata and the real SVG, not a second coordinate list in Python, supply reference positions. Radial X maps to SVG X; positive axial distance maps to negative SVG Y.
- A4 and US Letter pages: at least **10 mm** margins, **10 mm** overlap, alignment marks and a **100 mm** calibration bar. Print at **100% / Actual Size**.
- Verify the actual outline in final SVG and PDF physical coordinates, within **0.1 mm**; a correct calibration bar alone is insufficient.
- Fail explicitly on invalid dimensions, missing tools, failed rendering, unexpected output, or verification failure. Never create placeholder fabrication files.
- Physical coupon, adhesive, cap-retention, one-blade flop, and child carry checks remain mandatory. Digital checks do not establish impact safety.
- This folder is not a Git repository. Do not initialize Git or create a worktree solely for workflow compliance; commit steps are not applicable unless the owner separately requests Git.

## Review Focus

1. Measured pipe/foam differs from the nominal values: bore and slot must follow the inputs, while geometrically incompatible sizes fail explicitly — Task 1.
2. Blade length changes: station locations rescale, but 22 mm land heights do not; cap/land collisions are rejected — Task 1.
3. SVG/PDF units, reversed Y, and tile origins: the blade itself must retain physical scale, reference alignment, and complete page coverage — Task 2.
4. Missing tools, a nonzero exit, or OpenSCAD `ERROR:` text even with a zero exit: rendering must stop without publishing accepted artifacts — Tasks 1 and 2.
5. Regeneration and paths with spaces: reducing the page count must remove only obsolete generated pages, preserve unrelated files, and work outside the project cwd — Task 2.

## File Map

| File | Responsibility |
|---|---|
| `mace.scad` | Canonical blade profile, parameters, assertions, slotted ring, foam cap envelopes, assembly preview, metadata |
| `export.py` | OpenSCAD invocation, metadata extraction, styled/tiled SVG/PDF output, STL and final-pattern verification, CLI |
| `test_mace.py` | One `unittest` module covering the model and the actual export gate, including negative probes |
| `README.md` | Tool setup, regeneration, parameter names, printing, PVC layout, dry fitting, assembly, limitations |
| `SOURCES.md` | Existing research ledger; update only when additional verified references are used |
| `patterns/blade.svg` | Full-size annotated pattern; cutting path distinct from references |
| `patterns/blade-a4-NN.svg/.pdf` | Numbered A4 pages |
| `patterns/blade-letter-NN.svg/.pdf` | Numbered US Letter pages |
| `patterns/manifest.json` | Model-derived metadata, source fingerprint, generated filenames, page sizes and common-origin tile offsets |
| `prints/adapter.stl`, `prints/fit-coupon.stl` | Verified fabrication meshes |

The manifest is generated evidence for these exports, not a second configuration or hand-maintained geometry file. No pattern or STL is marked fabrication-ready until the real verification gate has passed.

---

## Prerequisite: Owner-installed tools

OpenSCAD and Poppler are absent. Ubuntu package candidates were confirmed: OpenSCAD `2021.01-6build4`, Poppler `24.02.0-1ubuntu9.9`. Passwordless sudo is unavailable, so the agent cannot perform this installation unattended.

- [ ] **Owner installs the two distro packages**, or supplies equivalent executables:

```bash
sudo apt-get install openscad poppler-utils
```

- [ ] **Verify tools before the feature test cycle:**

```bash
openscad --version
pdftocairo -v
python3 -c 'import cairosvg; print(cairosvg.__version__)'
```

Expected: successful version output and CairoSVG import. If package metadata is stale, the owner may need `sudo apt-get update` first. Do not request the owner's password, invent an installation fallback, or count a missing dependency as the intended TDD failure.

## Task 1: Parametric CAD and Render Contract

**Files:**
- Create: `mace.scad`
- Create: initial `export.py` render/metadata functions
- Create: `test_mace.py`, `TestCad`
- Create: initial `README.md` tool setup and model preview instructions

**Interfaces:**
- Consumes: approved spec and `SOURCES.md` drawing reference; installed OpenSCAD.
- Produces: `run_scad(mode: str, destination: Path, defines: dict[str, float] | None = None) -> None` and `read_model(defines: dict[str, float] | None = None) -> dict` in `export.py`.
- `run_scad` resolves `mace.scad` relative to `export.py`, uses argument arrays without a shell, honors an optional `OPENSCAD` executable override, and treats missing output or any OpenSCAD `ERROR:` as failure regardless of exit status.
- `read_model` parses one tagged `echo()` array beginning with `MACE_META` into a dictionary. Required keys: `parameters`, `blade_points`, `blade_bounds`, `bore_diameter`, `slot_width`, `stations`, `land_bands`, `pipe_span`, `top_cap_start`, `top_cap_radius`, and `svg_axes`. Names and values are echoed by SCAD, not recomputed from Python constants.
- SCAD public numeric names include `overall_length`, `blade_length`, `head_radius`, `pipe_od`, `bore_clearance`, `foam_thickness`, `slot_clearance`, `adapter_od`, `adapter_height`, `slot_root_radius`, `cover_allowance`, and the cap dimensions named in the README. Model modes: `blade_2d`, `metadata`, `adapter`, `fit_coupon`, `assembly`.

- [ ] **Step 1: Write the failing default-contract test** in `TestCad.test_defaults`:

```python
m = read_model()
self.assertEqual(m["blade_bounds"], [18.5, 0, 65, 295.275])
self.assertAlmostEqual(m["bore_diameter"], 27.17, places=3)
self.assertAlmostEqual(m["slot_width"], 10.5, places=3)
self.assertEqual(m["stations"], [45, 225])
self.assertEqual(m["land_bands"], [[34, 56], [214, 236]])
self.assertEqual(m["pipe_span"], [15, 854])
self.assertAlmostEqual(m["top_cap_start"], 245.275, places=3)
self.assertEqual(m["top_cap_radius"], 18)
self.assertEqual(m["svg_axes"], [1, -1])
```

Also pin `TestCad.test_measured_sizes`: `pipe_od=27` and `foam_thickness=12` produce a 27.5 mm bore and 12.5 mm slot without changing blade length. Pin `TestCad.test_scaled_stations_fixed_lands`: `blade_length=320` rescales stations by `320/295.275`, keeps both lands 22 mm high, and preserves cap separation. Write the negative and shape tests listed in Step 4 now, before implementing the corresponding guards.

- [ ] **Step 2: Run the red check:**

```bash
python3 -m unittest -v test_mace.TestCad
```

Expected initially: failure because the render/model interface does not exist, not because tool setup was skipped.

- [ ] **Step 3: Implement the canonical SCAD model and metadata/render interface.** Build an original polygon inspired by the reference drawing: elongated silhouette, swept outer lobes, outward inner reliefs, straight required mounting lands, and the approved bounds. No engraving or downloaded-model reuse. Use one blade module for both the cutting outline and centered foam extrusion. A common adapter module accepts height, giving the real ring and thin coupon; fabrication rings sit on Z=0, while assembly placement uses station center minus half ring height. Use one set of derived values for cap envelopes, preview, assertions, and metadata. Default preview is `assembly`.

Include SCAD assertions for positive dimensions, core wall, blade separation, cap/cover clearance, full 22 mm land stock beyond the ring perimeter, and cap/land separation. The radial insertion clearance follows from outward-moving profiles bounded outside the core and aligned slots; do not claim collision checking merely because a pretty preview renders. Python rejects non-finite numbers and unknown override names before accepting a render.

- [ ] **Step 4: Run the complete CAD gate, including its negative and shape checks.**

Names/assertions:
- `test_invalid_fit_rejected`: `pipe_od=34`, `foam_thickness=24`, and negative clearance each raise an explicit error.
- `test_short_blade_rejected`: `blade_length=240` is rejected because the top cap encroaches on the upper mounting region.
- `test_profile`: echoed point list is a single non-self-intersecting polygon with the required bounds and complete stock at both land bands; all point radii are at least 18.5 by default.
- `test_missing_tool`: unavailable `OPENSCAD` path raises an error, not fake metadata or a fake STL.
- `test_zero_exit_error_rejected`: a mocked zero-exit process containing `ERROR:` is rejected by the same `run_scad` used in production.
- `test_assembly_renders`: the actual `assembly` mode produces a nonempty temporary `.csg` file without render errors; it is never put in `prints/`.

Run `python3 -m unittest -v test_mace.TestCad`; expected: all tests pass. Render the actual blade SVG to a temporary PNG with existing CairoSVG and inspect it against the reference. If a display is available, also view the assembly in OpenSCAD; otherwise record that interactive visual check as an owner-side check, not as an action the headless agent performed. Visual inspection supplements, not replaces, geometric assertions.

- [ ] **Step 5: Record the task evidence.** List created files, red/green commands, visual-check result, and any remaining rendering limitations. Commit only if the owner has separately established Git; otherwise leave files in this project folder.

## Task 2: Verified Cutting Pages and Fabrication Exports

**Files:**
- Modify: `export.py`
- Modify: `test_mace.py`, add `TestExports`
- Modify: `README.md`
- Generate: `patterns/` and `prints/` files in the file map

**Interfaces:**
- Consumes: Task 1's `run_scad`, `read_model`, metadata keys, native `blade_2d` SVG, and the real `adapter`/`fit_coupon` modes.
- Produces: `build(output_dir: Path, defines: dict[str, float] | None = None) -> dict` and `validate_exports(output_dir: Path) -> None` in `export.py`. `build` returns the generated manifest and runs the real validator before publishing successful output.
- CLI: `python3 export.py [--out DIR] [--set NAME=NUMBER ...]`; default output root is the project folder, independent of caller cwd. `python3 export.py --check [--out DIR]` validates an existing export tree without regenerating it.
- Manifest supplies `cad` metadata and `pages` entries with format, physical size, SVG/PDF relative filenames, and common-origin offsets. Generated-file ownership is explicit; reject unsafe manifest paths rather than deleting outside `patterns/` or `prints/`.

- [ ] **Step 1: Write the failing export tests.** Write the corruption/failure probes listed in Step 4 before implementing the corresponding validator. `TestExports.test_default_exports` builds into a `TemporaryDirectory` and requires:

```python
result = build(output_dir)
validate_exports(output_dir)
self.assertEqual(result["cad"]["blade_bounds"], [18.5, 0, 65, 295.275])
self.assertTrue((output_dir / "patterns/blade.svg").is_file())
self.assertTrue((output_dir / "prints/adapter.stl").is_file())
self.assertTrue((output_dir / "prints/fit-coupon.stl").is_file())
self.assertEqual({p["format"] for p in result["pages"]}, {"a4", "letter"})
```

Require A4 page size `[210, 297]` mm and Letter `[215.9, 279.4]` mm, complete coverage with at least 10 mm margins and 10 mm overlap, and an exactly 100 mm calibration bar. Default blade paths reconstruct to 295.275 × 46.5 mm within 0.1 mm in final SVG **and PDF** coordinates. Dashed mounting marks must correspond to the echoed stations and bands after the declared X/Y transform.

- [ ] **Step 2: Run the red check:**

```bash
python3 -m unittest -v test_mace.TestExports
```

Expected initially: failure because `build` and `validate_exports` are not implemented.

- [ ] **Step 3: Implement actual exports and their validator.** Use the real SCAD-exported SVG path and its viewBox. Add references solely from metadata. Give the cutting outline black styling, mounting references blue/dashed, labels and alignment marks gray, and the calibration bar red; the grayscale legend must still distinguish cut from reference lines. Keeping only cutting geometry black also lets PDF inspection identify the actual outline rather than annotation glyphs.

Tile the common physical coordinate space without scaling it to page width. Use explicit millimeter page sizes and store each tile origin in the manifest. CairoSVG converts each numbered SVG into its numbered PDF; no PDF merger. Render both STLs from their own modes, explicitly requesting ASCII STL for the small standard-library mesh check if supported by the verified OpenSCAD version.

For PDF measurement, invoke **`pdftocairo -svg`** on the actual PDF and measure its black cutting paths after SVG group transforms and physical-unit conversion. Reconstruct tile bounds using recorded origins. Parse the straight-line path output needed here; fail on unexpected unsupported commands instead of writing a generic PDF parser or assuming scale. PDF inspection and publication require Poppler, not just CairoSVG.

Verify the real mesh triangles: nonempty, one connected closed component, correct height (16 mm or 5 mm), no pipe/cap/other assembly geometry, centered open bore, and six open radial slots. Use welded vertex/edge checks and representative interior/exterior probes; do not assume nominal 60 mm OD implies a 60 mm X bounding box after the radial slots remove its extremes.

Generate in a unique temporary staging directory, run the same `validate_exports` there, then publish the known artifact set. On regeneration, remove only obsolete files recorded as owned by the prior manifest; preserve unrelated files. No generic deployment/transaction framework.

- [ ] **Step 4: Run the real-gate failure probes and prove they bind.**

Names/assertions:
- `test_svg_scale_corruption`: modify only the exported cut-outline transform to 90% scale, leaving the calibration bar unchanged; `validate_exports` raises an error.
- `test_pdf_scale_corruption`: produce a PDF from a 90%-scaled cut layer while leaving the corresponding canonical SVG, metadata, and bar unchanged; PDF inspection makes `validate_exports` fail.
- `test_missing_pdf_tool`: unavailable `pdftocairo` produces a clear verification error and no successful publication.
- `test_stl_contamination`: a missing mesh, disconnected extra solid, or cap/pipe-sized contaminating mesh is rejected rather than treated as a valid ring.
- `test_stations_on_pages`: reference positions survive negative-Y mapping and tile translation and remain non-cut markings.
- `test_page_count_changes`: use a valid long `blade_length=700`, then regenerate defaults; page counts change, stale owned numbered pages disappear, and an unrelated note remains.
- `test_paths_and_cwd`: build and validate a directory containing spaces while running from another cwd; no shell interpretation or accidental writes there.

Run the full `python3 -m unittest -v`; expected: all tests pass. Also run the actual CLI gate, `python3 export.py --check --out PROBE_DIR`, on the deliberately scale-corrupted temporary SVG/PDF trees: require a nonzero exit identifying outline scale, then restore and require a zero exit. Each corruption is isolated in a temporary copy and restored/rebuilt; never leave a deliberate probe in the user's fabrication outputs.

- [ ] **Step 5: Generate and inspect the actual deliverables.**

```bash
python3 export.py
python3 export.py --check
python3 -m unittest -v
```

Expected: verified blade SVG, A4/Letter PDF pages, manifest, adapter STL and coupon STL; all tests pass. Render and inspect at least one page from each paper format and the full blade to catch inverted marks, clipped labels, or poor silhouette. Inspect the assembly in OpenSCAD when a display is available; otherwise deliver the tested assembly preview source and explicitly leave its interactive visual check to the owner. Measure the path, not a screenshot, for acceptance. Record each output's actual dimensions and page counts instead of predicting them in the README.

- [ ] **Step 6: Finish the fabrication instructions in `README.md`.** Explain `OPENSCAD`, numeric `--set` overrides, regeneration/check commands, actual output filenames/page counts, Actual Size printing and ruler calibration, printing one coupon first, two identical adapters, and the 839 mm provisional PVC layout. Document the foam cap cavities and bare-pipe seating, glue compatibility/scrap tests, one-blade mockup, cap retention, child carry check, and venue rules. Do not imply measured physical comfort or joint strength from digital passing checks.

- [ ] **Step 7: Record task evidence and preserve the known limitations.** Include real red/green and corruption-probe results, outputs generated, tool versions, inspections, and residual physical checks. Commit only if Git has been separately authorized.

## Final Independent Review and Handoff

- [ ] Re-run the exact final commands above and collect their output before requesting review.
- [ ] For recommended native execution, use **one fresh Opus 5.5 reviewer at the operator's selected medium effort**, in a read-only shell-capable route. Proposed route: a Paseo Claude agent in Plan Mode, in the verified local workspace for `/home/kurtt/sauron-cosplay`. Execution approval must include this route; do not silently replace the governed runner or select a different model.
- [ ] Verify the agent's actual model and workspace with `paseo inspect`; give it the approved spec, four product source files, generated manifest and output paths, and gate evidence. Allow only read-only inspection and the verification commands; no edits, publication, or nested delegation. Since no Git branch exists, review the complete product-file/output set rather than inventing a branch diff.
- [ ] Treat only an actual completed verdict as review completion. A `paseo wait` status other than `idle`, a runner failure, or an unanswered permission request is a blocker, not a clean review. Verify supported findings and fix in the primary session, then rerun affected gates. Do not automatically review this implementation-plan document.
- [ ] Deliver the CAD source, blade SVG/PDF links, two STL links, sources ledger, verified dimensions, and a short list of physical checks still required. Do not claim the prop has been printed or physically tested.

## Plan Self-Review

- [x] Spec coverage: CAD/interface and caps in Task 1; marking, tiling, both physical-scale checks and meshes in Task 2; physical fabrication sequence in README.
- [x] Interfaces: render/metadata functions belong to Task 1; build/validation/CLI consume them in Task 2; metadata names agree across the tasks.
- [x] Review Focus: all five listed input/failure classes have named tests in their owning tasks.
- [x] Proportion: two coupled implementation tasks, four product source files, native tools for PDF inspection, no added framework or wholesale copied implementation.
- [x] Environment: package candidates checked; installation requires the owner; no installation, product code, or fabricated exports performed during planning.
- [ ] User reviews the written plan and selects native or subagent-driven execution.

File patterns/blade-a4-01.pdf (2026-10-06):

Sauron blade | A4 1/2 | Actual Size / 100%
SOLID BLACK: cut. DASHED BLUE: mount references, not cuts. GRAY: alignment.

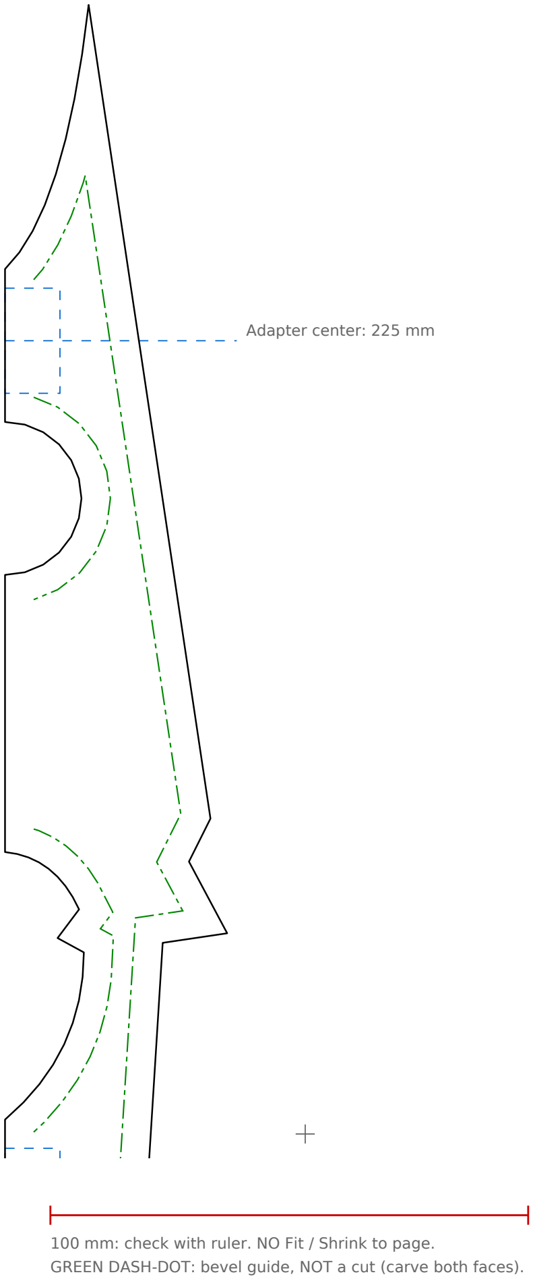
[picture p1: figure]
Adapter center: 225 mm

100 mm: check with ruler. NO Fit / Shrink to page.
GREEN DASH-DOT: bevel guide, NOT a cut (carve both faces).

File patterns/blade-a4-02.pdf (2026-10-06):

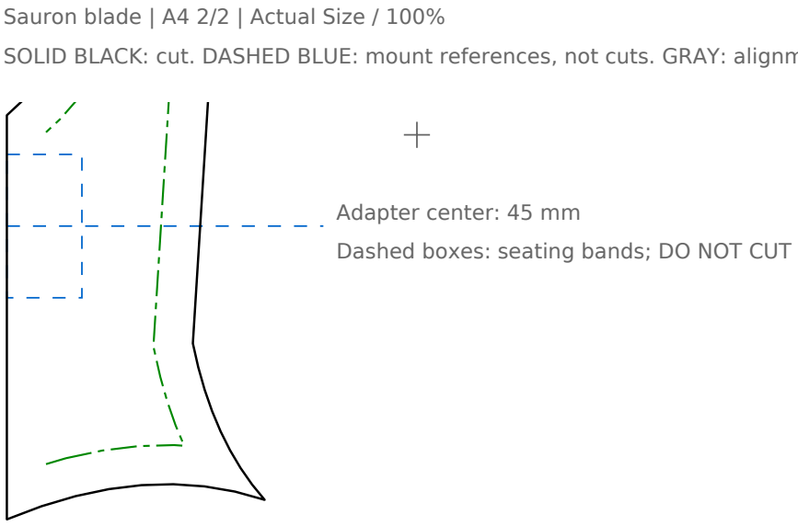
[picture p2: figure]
Adapter center: 45 mm; Dashed boxes: seating bands; DO NOT CUT

Sauron blade | A4 2/2 | Actual Size / 100%
SOLID BLACK: cut. DASHED BLUE: mount references, not cuts. GRAY: alignment.

100 mm: check with ruler. NO Fit / Shrink to page.
GREEN DASH-DOT: bevel guide, NOT a cut (carve both faces).

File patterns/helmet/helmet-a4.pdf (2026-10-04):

# SAURON | 01 FRAME & DETAILS

PAPER FIT ONLY | nominal band 540 mm | not a fitted foam pattern

Cut one master per shape; trace mirrored pairs onto spare paper.

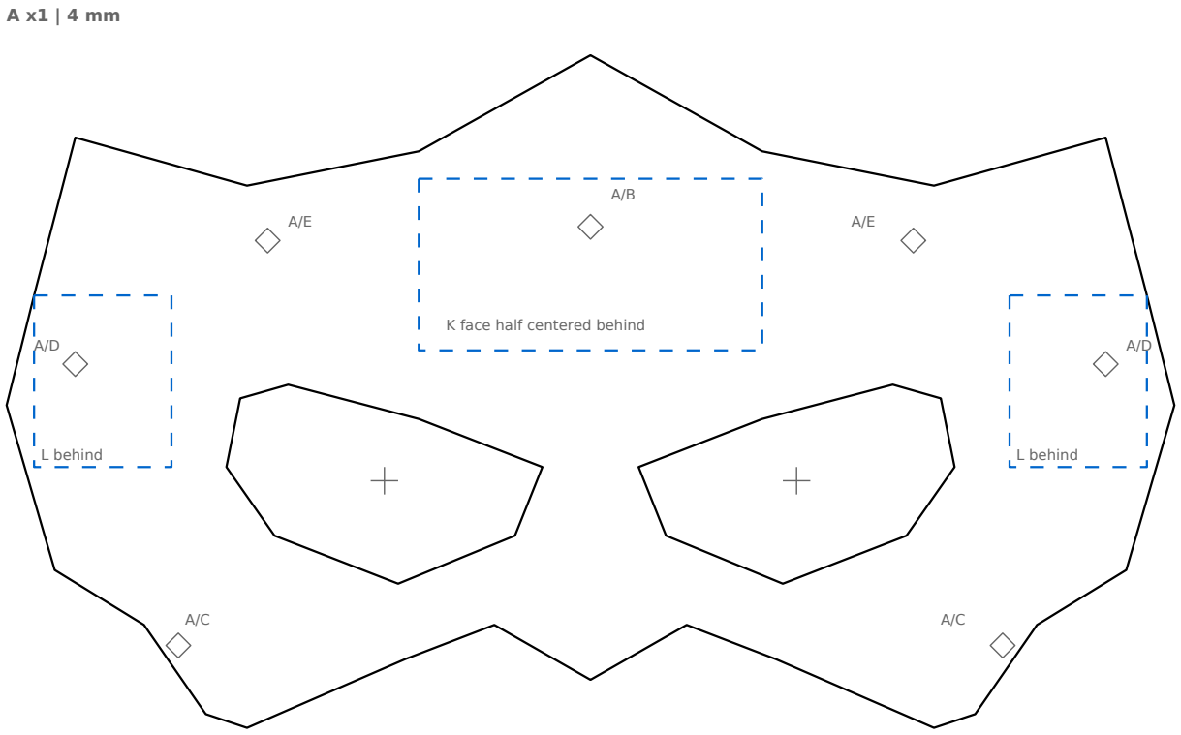
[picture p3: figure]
K face half centered behind; L behind

BLACK solid: cut | BLUE dashed: place/bond | GREEN dash-dot: form, do not cut
100 mm at 100% | Actual Size; NO Fit/Shrink | Sheet 1/5

A: cut both eye openings. Nominal eye-center spacing 60 mm; adjust on wearer.

A/E

E x2 MIRROR | 2 mm

FACE

behind A

BAND

half

K x1 | 4-6 mm

TEMPLE

tab

L x2 | 4-6 mm

B/G

G x1 | 2 mm

E/G: optional overlays.

K/L: fold to set face stand-off.

Diamonds: match same label.

Fit the unadorned mask first.

L: turn 90 degrees to fit blue boxes.
Suggested foam thicknesses apply only after paper fitting.

A4

# SAURON | 02 SPLIT FACE & CHEEKS

C and C2: cut one left + one right by flipping the template.

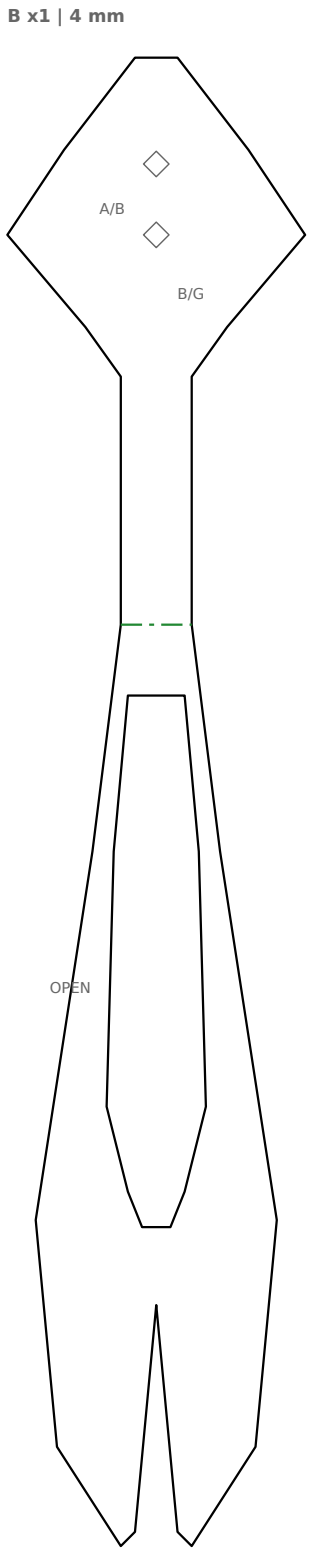
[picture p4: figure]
OPEN

BLACK solid: cut | BLUE dashed: place/bond | GREEN dash-dot: form, do not cut
100 mm at 100% | Actual Size; NO Fit/Shrink | Sheet 2/5

A/C

C2.1

C2.2

C x2 MIRROR | 4 mm

C2.1

C2.2

C2 x2 MIRROR | 2 mm

C2 is placed on C using the two matching diamonds.

# SAURON | 03 TEMPLES & CENTER SPIRES

S1: front center | S2: rear center | D: mirrored side plates.
BLACK solid: cut | BLUE dashed: place/bond | GREEN dash-dot: form, do not cut
100 mm at 100% | Actual Size; NO Fit/Shrink | Sheet 3/5

A/D

D x2 MIRROR | 4 mm

25 mm root

included

S1 x1 | 4 mm

25 mm root

included

S2 x1 | 4 mm

Spire roots are INCLUDED.

Form shallow open V ridges.

Never add rigid cores.

S2 rear root must not bridge the reachable rear band overlap.

# SAURON | 04 PAIRED SPIRES & SUPPORT

S3: tall side pair | S4: shorter forward pair | H: paper strips.
BLACK solid: cut | BLUE dashed: place/bond | GREEN dash-dot: form, do not cut
100 mm at 100% | Actual Size; NO Fit/Shrink | Sheet 4/5

25 mm root

included

S3 x2 MIRROR | 4 mm

25 mm root

included

S4 x2 MIRROR | 4 mm

20 join

60 rear

20 join

H x6 | PAPER

PAPER

165 x 25

strip

H x4: 3 joints at 20 mm = 600 mm.

Rear overlap 60 mm = 540 mm loop.

H x2: 20 mm join = 310 mm strap.

20 mm ends leave 270 mm over head.

All support lengths remain adjustable.

# SAURON | 05 ASSEMBLY KEY

REFERENCE ONLY / DO NOT CUT | schematic placement, not a verified 3D assembly.

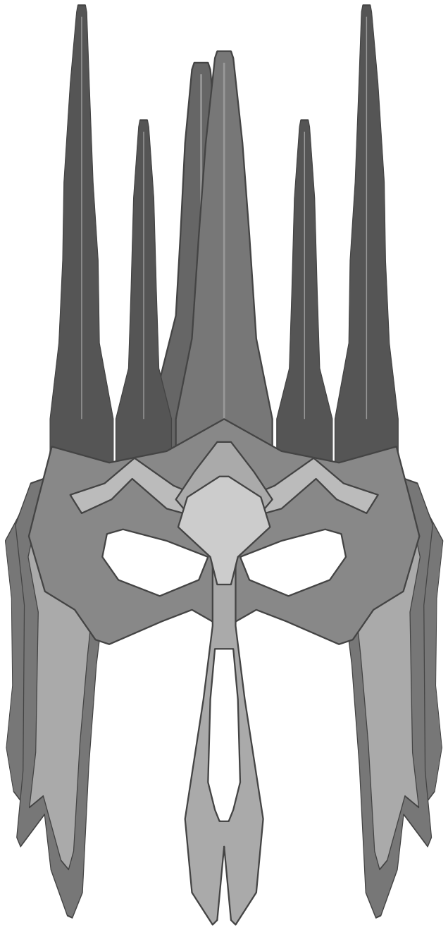
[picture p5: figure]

BLACK solid: cut | BLUE dashed: place/bond | GREEN dash-dot: form, do not cut

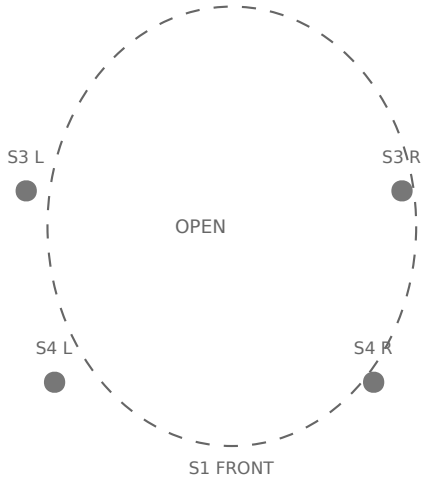
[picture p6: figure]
OPEN; S1 FRONT

100 mm at 100% | Actual Size; NO Fit/Shrink | Sheet 5/5
Layered front appearance | Crown positions

S2 REAR

Three connections to support:

K forehead + L at both temples.

Do not hang from temples alone.

Layer order / placement anchors:

A frame + B center: A/B

C cheeks on A: A/C

D temples behind A/C: A/D

E brow ridges on A: A/E

G forehead accent on B: B/G

C2 inset on C: C2.1 / C2.2

L tabs: blue side boxes behind A

Six spires: S1 + S2 + 2S3 + 2S4

Paper test: vision, breathing, pressure, clearance, balance and unaided removal.

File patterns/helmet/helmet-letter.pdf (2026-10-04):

# SAURON | 01 FRAME & DETAILS

PAPER FIT ONLY | nominal band 540 mm | not a fitted foam pattern

Cut one master per shape; trace mirrored pairs onto spare paper.

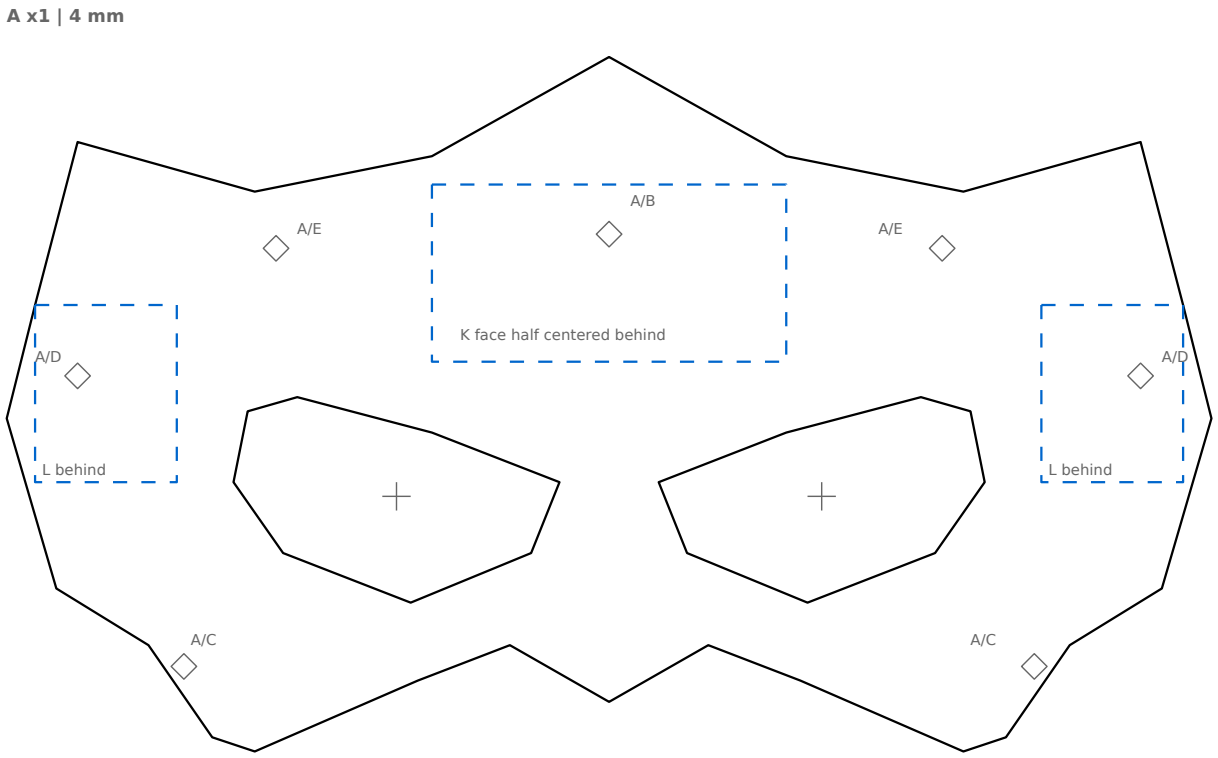
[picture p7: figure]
K face half centered behind; L behind

BLACK solid: cut | BLUE dashed: place/bond | GREEN dash-dot: form, do not cut
100 mm at 100% | Actual Size; NO Fit/Shrink | Sheet 1/5

A: cut both eye openings. Nominal eye-center spacing 60 mm; adjust on wearer.

A/E

E x2 MIRROR | 2 mm

FACE

behind A

BAND

half

K x1 | 4-6 mm

TEMPLE

tab

L x2 | 4-6 mm

B/G

G x1 | 2 mm

E/G: optional overlays.

K/L: fold to set face stand-off.

Diamonds: match same label.

Fit the unadorned mask first.

L: turn 90 degrees to fit blue boxes.
Suggested foam thicknesses apply only after paper fitting.

LETTER

# SAURON | 02 SPLIT FACE & CHEEKS

C and C2: cut one left + one right by flipping the template.

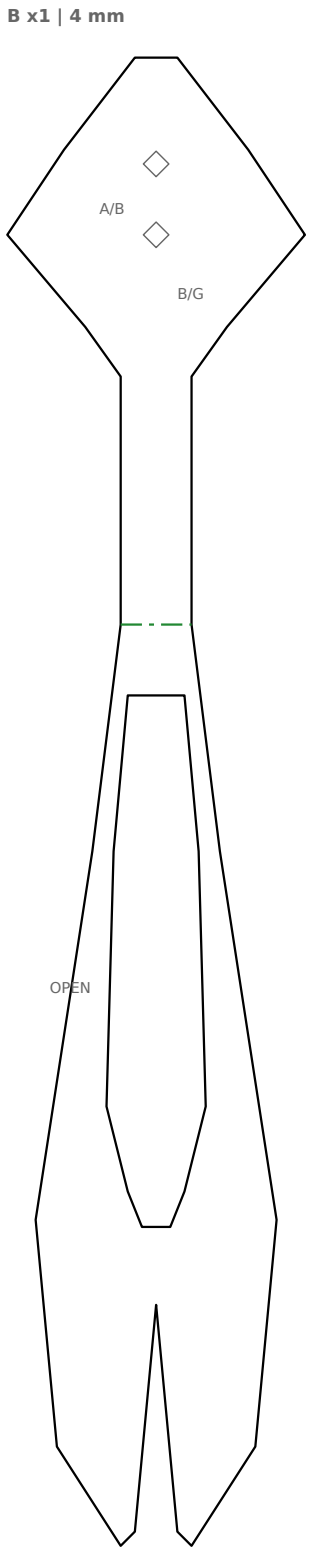
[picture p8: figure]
OPEN

A/C

C2.1

C2.2

C x2 MIRROR | 4 mm

C2.1

C2.2

C2 x2 MIRROR | 2 mm

C2 is placed on C using the two matching diamonds.

# SAURON | 03 TEMPLES & CENTER SPIRES

S1: front center | S2: rear center | D: mirrored side plates.

A/D

D x2 MIRROR | 4 mm

25 mm root

included

S1 x1 | 4 mm

25 mm root

included

S2 x1 | 4 mm

Spire roots are INCLUDED.

Form shallow open V ridges.

Never add rigid cores.

S2 rear root must not bridge the reachable rear band overlap.

# SAURON | 04 PAIRED SPIRES & SUPPORT

S3: tall side pair | S4: shorter forward pair | H: paper strips.

25 mm root

included

S3 x2 MIRROR | 4 mm

25 mm root

included

S4 x2 MIRROR | 4 mm

20 join

60 rear

20 join

H x6 | PAPER

PAPER

165 x 25

strip

H x4: 3 joints at 20 mm = 600 mm.

Rear overlap 60 mm = 540 mm loop.

H x2: 20 mm join = 310 mm strap.

20 mm ends leave 270 mm over head.

All support lengths remain adjustable.

# SAURON | 05 ASSEMBLY KEY

REFERENCE ONLY / DO NOT CUT | schematic placement, not a verified 3D assembly.
Layered front appearance | Crown positions

S2 REAR

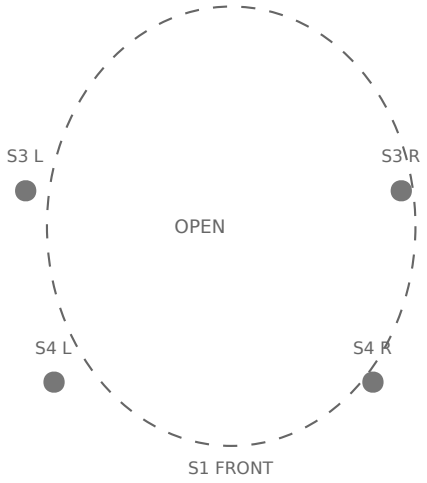
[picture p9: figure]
OPEN; S1 FRONT

Three connections to support:

K forehead + L at both temples.

Do not hang from temples alone.

Layer order / placement anchors:

A frame + B center: A/B

C cheeks on A: A/C

D temples behind A/C: A/D

E brow ridges on A: A/E

G forehead accent on B: B/G

C2 inset on C: C2.1 / C2.2

L tabs: blue side boxes behind A

Six spires: S1 + S2 + 2S3 + 2S4

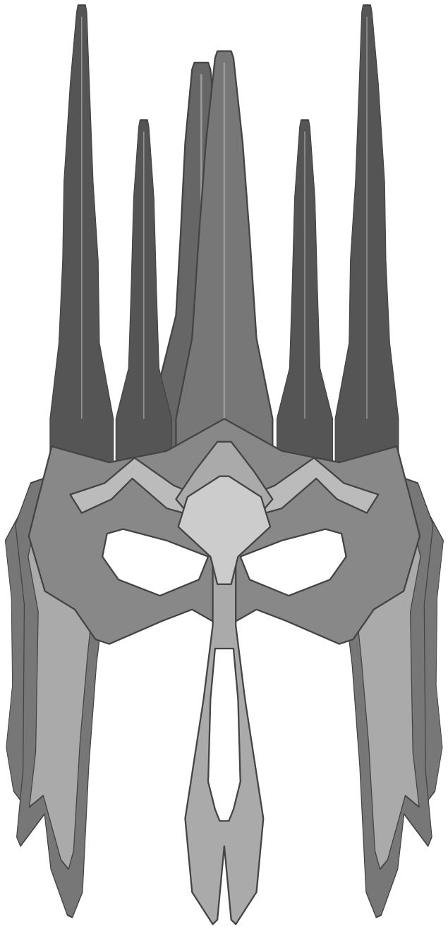
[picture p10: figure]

Paper test: vision, breathing, pressure, clearance, balance and unaided removal.

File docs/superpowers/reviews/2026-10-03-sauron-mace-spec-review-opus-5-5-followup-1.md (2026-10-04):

# Sauron Mace Spec: Focused Follow-up Review (Opus 5.5)

**Subject:** `docs/superpowers/specs/2026-10-03-sauron-mace-design.md`, SHA256 `c048bce9…1551`, checked against the supplied packet. This was a text-only review. I used no tools and wrote no file, so the host should save this answer to the configured output path.

## Geometry and caps (prior gaps 1 and 2)

**Gap 1 (blade inner radius) is resolved.** The whole outline is now required to stay at radius 18.5 or more. Reliefs must move away from the axis, and inward-curled tips are banned. The arithmetic is consistent:
- Bore radius is 27.17 / 2 = 13.585, so the wall is 18.5 − 13.585 = 4.915. That meets the ≥3 requirement.
- Covered pipe radius is 13.335 + 3 = 16.335. Adding the 0.5 gap gives 16.835, which is below 18.5.
- Cap radius is 18, which leaves exactly 0.5 to the blade root.

The whole foam volume and the radial insertion path are now checked against the pipe, wrapping and caps. Adjacent blades are checked against each other, and intended contact inside the slots is allowed.
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

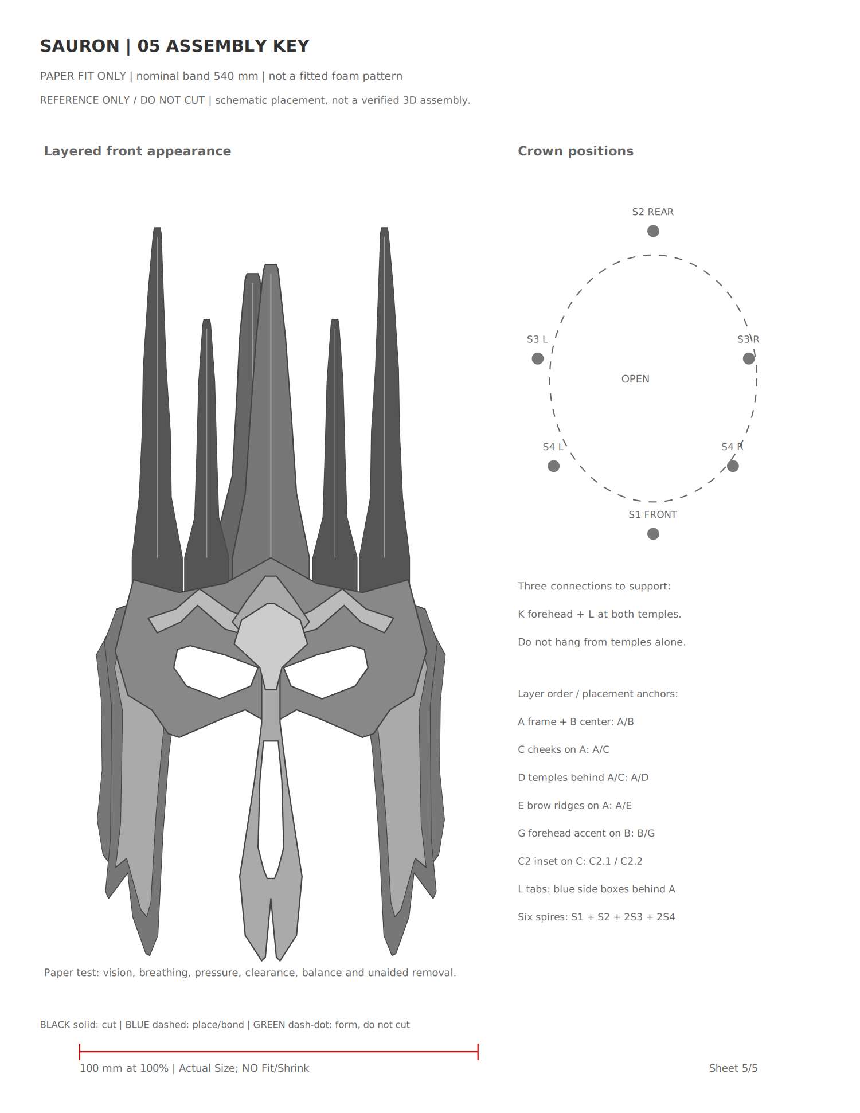
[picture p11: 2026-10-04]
patterns/helmet/preview.png

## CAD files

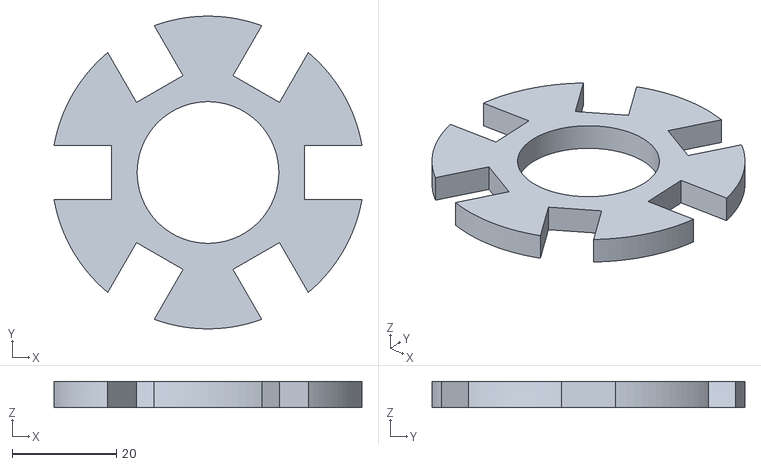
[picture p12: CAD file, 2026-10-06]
prints/fit-coupon.stl
59.1 x 60.0 x 5.00

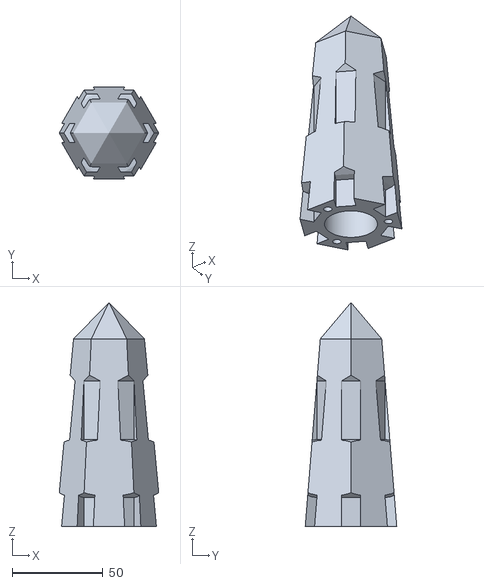
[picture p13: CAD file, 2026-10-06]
prints/holder-upper.stl
54.7 x 50.3 x 123.1

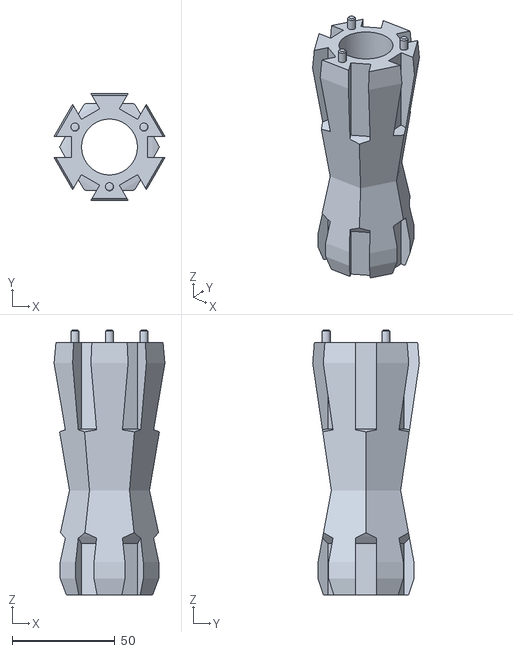
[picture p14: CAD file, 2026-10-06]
prints/holder-lower.stl
54.1 x 52.0 x 129.1

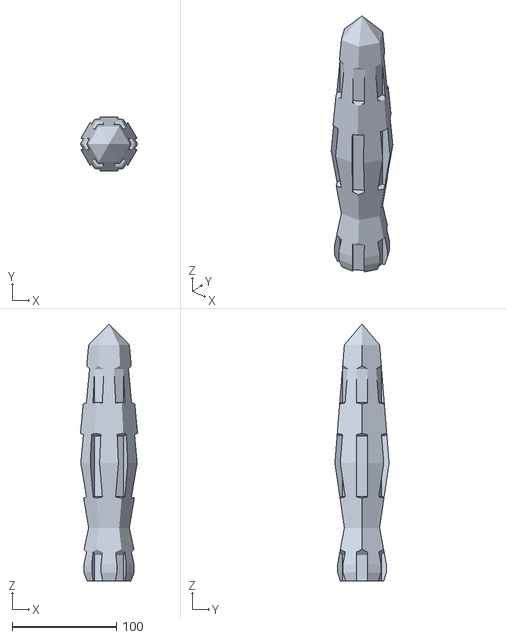
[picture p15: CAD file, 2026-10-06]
prints/holder.stl
54.7 x 52.0 x 246.3

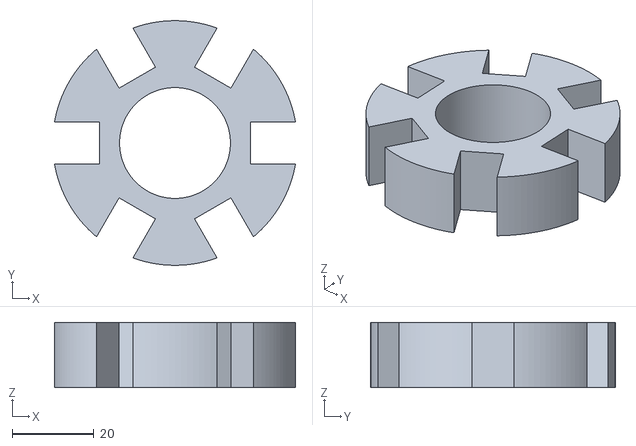
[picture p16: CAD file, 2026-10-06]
prints/adapter.stl
59.1 x 60.0 x 16.0

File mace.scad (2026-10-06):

// Child-sized Sauron carrying/photo prop. Millimeters; see README.md and SOURCES.md.
// Print holder_lower and holder_upper once each, fit_coupon once.
// Crown is printed to a point, recessed inside separate EVA blades.
// Pommel is FOAM. Legacy rings + foam top cap remain a lighter alternative.
mode = "assembly"; // [assembly,ring_assembly,blade_2d,metadata,adapter,fit_coupon,holder,holder_lower,holder_upper]
overall_length = 889;
blade_length = 295.275;
head_radius = 65;
pipe_od = 26.67;
bore_clearance = 0.5; // Total DIAMETER allowance
foam_thickness = 10;
slot_clearance = 0.3; // Total slot WIDTH allowance
adapter_od = 60;
adapter_height = 16;
slot_root_radius = 18.5;
cover_allowance = 3;
land_allowance = 3;
coupon_height = 5;
tip_od = 36;
tip_overlap = 15;
tip_extension = 35;
tip_end_radius = 4; // Legacy foam top-cap tip radius
crown_recess = 12; // Printed crown ends this far below EVA blade tips
pin_d = 4; // Printed joint alignment pins on the lower section
pin_length = 6;
pin_clearance = 0.4; // Total hole DIAMETER allowance
pommel_od = 40;
pommel_height = 40;
pommel_extension = 15;
$fn = 128;

bore_diameter = pipe_od + bore_clearance;
slot_width = foam_thickness + slot_clearance;
adapter_radius = adapter_od / 2;
land_half = adapter_height / 2 + land_allowance;
axial_scale = blade_length / 295.275;
stations = [45 * axial_scale, 225 * axial_scale];
land_bands = [for (s = stations) [s - land_half, s + land_half]];
blade_base = overall_length - blade_length;
pipe_start = pommel_extension;
pipe_end = overall_length - tip_extension;
top_cap_start = blade_length - tip_extension - tip_overlap;
cover_radius = pipe_od / 2 + cover_allowance;
holder_start = stations[0] - adapter_height/2;
holder_body_end = stations[1] + adapter_height/2;
holder_body_height = holder_body_end - holder_start;
holder_end = blade_length - crown_recess;
holder_height = holder_end - holder_start;
holder_bore_height = pipe_end - blade_base - holder_start + 1; // 1 mm axial PVC slack
crown_stem_z = holder_bore_height + 2; // Protect the pipe wall before the outer cone narrows
holder_split = (holder_start + holder_end)/2;
// Reference spindle (drawing's 380 mm core), placed for blade D: base collar on
// the base root, 19.5 mm waist inside the lower opening, the 60 mm hexagonal swell
// over the solid middle root (118-176 mm), then one taper through the round bite.
// Blades sit at the six vertices; the final taper keeps 3 mm of wall around the
// PVC end before the point.
holder_profile = [
    [slot_root_radius+5.5, 0],
    [adapter_radius-3, z(45)-holder_start],
    [adapter_radius-3, z(53)-holder_start],
    [slot_root_radius+1, z(88)-holder_start],
    [adapter_radius, z(150)-holder_start],
    [slot_root_radius+1, crown_stem_z],
    [0, holder_height]
];
function profile_r(z, i=0) = z <= holder_profile[i+1][1]
    ? holder_profile[i][0] + (holder_profile[i+1][0]-holder_profile[i][0])*(z-holder_profile[i][1])/(holder_profile[i+1][1]-holder_profile[i][1])
    : profile_r(z, i+1);
// Pins sit midway between bore and hexagon flats at the joint, on the flat
// directions so they stay clear of the vertex grooves.
pin_circle = (bore_diameter/2 + profile_r(holder_height/2)*cos(30))/2;
function r(f) = slot_root_radius + (head_radius - slot_root_radius) * f;
function z(y) = y * axial_scale;

// Blade D, "spiked", adapted from the United Cutlery PD4646 drawing: sturdy body,
// spear tip, round bite and barbed opening open to the shaft, hooked outer spike
// and a crescent base horn. Design coordinates are default-size millimeters
// (x = 18.5 slot root .. 65 head radius, y = 0 .. 295.275 tip), mapped through
// r()/z() so head_radius, blade_length and slot_root_radius stretch the outline.
function design(points) = [for (p = points) [r((p[0] - 18.5) / 46.5), z(p[1])]];
// Quadratic Bezier, n segments, endpoints included.
function bez(p0, c, p1, n=8) = [for (i = [0:n]) let(t = i / n) (1-t)*(1-t)*p0 + 2*(1-t)*t*c + t*t*p1];
// Circular arc from angle a0 to a1 (degrees), endpoints included.
function arc(center, radius, a0, a1, n=12) = [for (i = [0:n]) let(a = a0 + (a1 - a0) * i / n) center + radius * [cos(a), sin(a)]];
function head(v) = [for (i = [0:len(v)-2]) v[i]];
function tail(v) = [for (i = [1:len(v)-1]) v[i]];
blade_points = design(concat(
    head(bez([18.5, 0], [40, 9], [58, 3])),
    head(bez([58, 3], [50, 12], [47, 27])),
    [[47, 27], [51.5, 99], [65, 101], [57, 116], [61.5, 125], [36, 295.275]],
    tail(bez([36, 295.275], [31, 252], [18.5, 240])),
    arc([18.5, 192], 16, 90, -90, 12),
    bez([18.5, 118], [29, 117], [34, 106]),
    [[29.5, 100], [35, 97]],
    tail(bez([35, 97], [35, 76], [18.5, 62]))
));
// Inner edge, tip to base: its radial shadow is the only groove in the holder.
blade_tip = [for (i = [0:len(blade_points)-1]) if (blade_points[i][1] == max([for (p = blade_points) p[1]])) i][0];
blade_inner_edge = [for (i = [blade_tip:len(blade_points)-1]) blade_points[i], blade_points[0]];
parameters = [
    ["overall_length", overall_length], ["blade_length", blade_length],
    ["head_radius", head_radius], ["pipe_od", pipe_od],
    ["bore_clearance", bore_clearance], ["foam_thickness", foam_thickness],
    ["slot_clearance", slot_clearance], ["adapter_od", adapter_od],
    ["adapter_height", adapter_height], ["slot_root_radius", slot_root_radius],
    ["cover_allowance", cover_allowance], ["land_allowance", land_allowance],
    ["coupon_height", coupon_height], ["tip_od", tip_od],
    ["tip_overlap", tip_overlap], ["tip_extension", tip_extension],
    ["tip_end_radius", tip_end_radius], ["crown_recess", crown_recess], ["pin_d", pin_d], ["pin_length", pin_length],
    ["pin_clearance", pin_clearance], ["pommel_od", pommel_od],
    ["pommel_height", pommel_height], ["pommel_extension", pommel_extension]
];

assert(overall_length > blade_length && blade_length > 0, "overall/blade length");
assert(pipe_od > 0 && foam_thickness > 0 && adapter_height > 0, "positive sizes");
assert(bore_clearance >= 0 && slot_clearance >= 0, "negative clearance");
assert(cover_allowance >= 0 && land_allowance >= 3, "cover/land allowance");
assert(head_radius > adapter_radius && adapter_radius > slot_root_radius, "head/ring/slot radii");
assert(slot_root_radius - bore_diameter / 2 >= 3, "minimum core wall 3 mm");
assert(slot_width < 2 * slot_root_radius * tan(30), "adjacent slot/blade separation");
assert(slot_root_radius >= cover_radius + .5, "covered pipe clearance");
assert(slot_root_radius >= tip_od / 2 + .5, "foam tip clearance");
assert(tip_od > bore_diameter && tip_overlap > 0 && tip_extension > 0, "tip sleeve");
assert(tip_end_radius >= 3 && tip_end_radius <= tip_od / 2, "rounded tip radius at least 3 mm");
assert(pommel_od > bore_diameter && pommel_extension > 0 && pommel_height > pommel_extension, "pommel sleeve");
assert(blade_base > pommel_height, "blade/pommel separation");
assert(coupon_height > 0 && coupon_height <= adapter_height, "coupon height");
assert(land_bands[0][1] < z(62), "lower root must cover lower band");
assert(land_bands[1][0] > z(208) && land_bands[1][1] < z(240), "upper root must cover upper band");
assert(r((44.5-18.5)/46.5) > adapter_radius, "radial land stock");
assert(top_cap_start > land_bands[1][1], "cap/upper land separation");
assert(min([for (p = holder_profile) if (p[1] <= crown_stem_z) p[0]])*cos(30) - bore_diameter/2 >= 3, "minimum hexagonal holder wall 3 mm");
assert(crown_recess > 0 && holder_body_height < crown_stem_z && crown_stem_z < holder_height, "crown/pipe/blade-tip clearance");
assert(max([for (p = holder_profile) p[0]]) <= adapter_radius, "holder shoulders require larger adapter_od");
assert(pin_d >= 3 && pin_length >= 3 && pin_clearance >= 0 && pin_length + 1 < holder_height/2, "joint pin size");
assert(min(pin_circle - bore_diameter/2, profile_r(holder_height/2)*cos(30) - pin_circle) - (pin_d+pin_clearance)/2 >= 1.2, "joint pin wall 1.2 mm");
// Blade inner-edge radius at blade-local z (edge runs tip to base).
function inner_r(z, i=0) = z >= blade_inner_edge[i+1][1]
    ? blade_inner_edge[i+1][0] + (blade_inner_edge[i][0]-blade_inner_edge[i+1][0])*(z-blade_inner_edge[i+1][1])/(blade_inner_edge[i][1]-blade_inner_edge[i+1][1])
    : inner_r(z, i+1);
assert(profile_r(holder_height/2) <= inner_r(holder_split) || pin_circle*sin(30) - (pin_d+pin_clearance)/2 >= slot_width/2 + .5,
    "joint pins clear of vertex grooves");
assert(holder_start >= 0 && holder_body_end < top_cap_start, "holder/legacy foam cap separation");
assert(mode == "assembly" || mode == "ring_assembly" || mode == "blade_2d" || mode == "metadata" || mode == "adapter" || mode == "fit_coupon" || mode == "holder" || mode == "holder_lower" || mode == "holder_upper", "unknown mode");
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

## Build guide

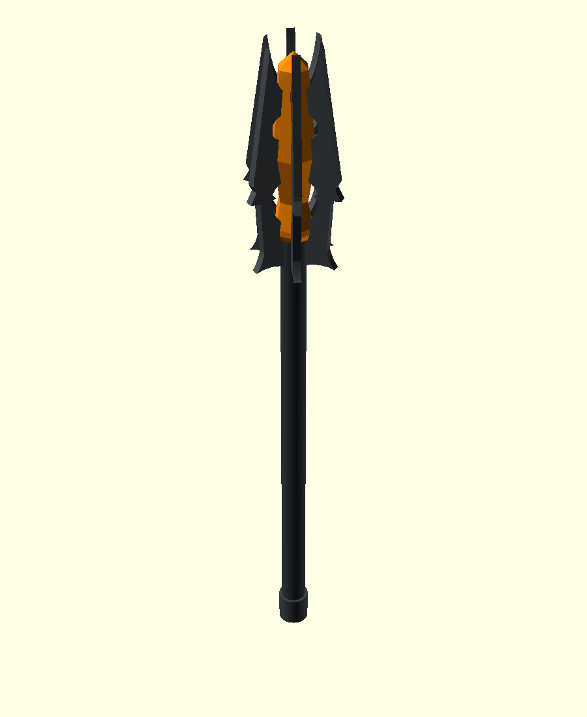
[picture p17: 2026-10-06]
prints/assembly-holder-preview.png

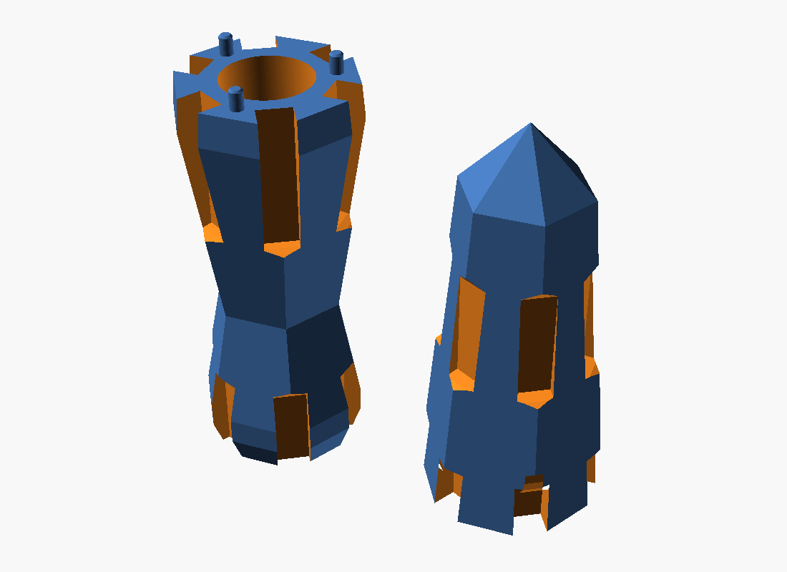
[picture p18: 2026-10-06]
prints/holder-sections-preview.png

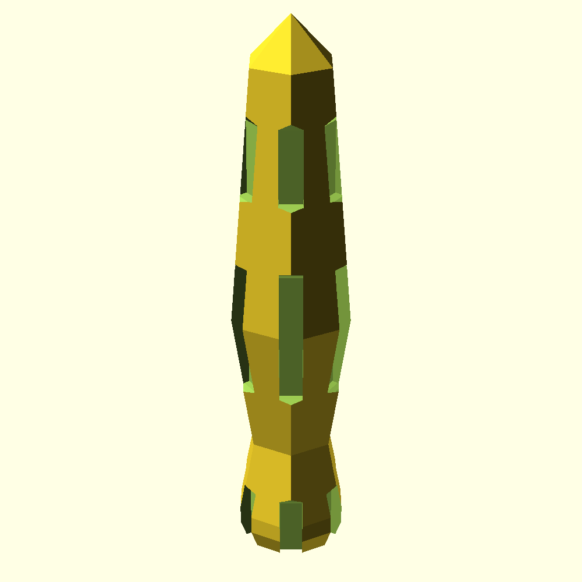
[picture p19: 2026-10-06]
prints/holder-preview.png

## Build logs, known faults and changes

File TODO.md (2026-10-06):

# Tapered blade holder

- [x] Explore existing OpenSCAD model, build instructions, and reference drawing.
- [x] Confirm printer envelope and required blade compatibility: Bambu A1 mini, 180 mm cube; preserve existing approximately 3/4-scale prop and blade geometry.
- [x] Present short in-chat design, including print orientation and verification.
- [x] Obtain approval; user corrected split direction to perpendicular to the handle axis: two stacked sections, printed upright and aligned by the PVC. Subsequent explicit requirements: hexagonal cross section with blades at vertices, integrated rounded printed crown below the protruding EVA tips. Extended sections are now approximately 123 mm each.
- [x] Implement minimal geometry and regression checks: shared slots and mesh inspection, plus three holder modes.
- [x] Render/export and verify each part is a closed connected mesh; document upright print settings and physical-fit limitations.
- [x] Complete independent Anthropic review of the first holder revision and dispose substantive findings: explicit assembly orientation, channel-width gate, corrected wall description.
- [x] Implement requested hexagonal body and integrated rounded printed cone, with unchanged EVA outline / PVC cut and no overlapping legacy foam cap.
- [ ] Complete focused independent review of the final hexagon/crown revision.
- [x] Reshape holder to the drawing's 380 mm core spindle (collar, waist, single 60 mm swell, long taper) and replace full-length vertex channels with grooves cut only where each blade's inner edge meets the core (blade-local ~37–80 and ~183–250 mm). Profile/groove test watched fail first; validator now probes solid vertices outside grooves and groove floors on the blade inner edge, and rejects a full-channel mesh.
- [x] Removed the 4 mm crown ball per user; the cone now ends in a hexagonal point at the same 12 mm recess. Still exported as two upright ~123 mm sections.
- [x] Added joint alignment: three 4 × 6 mm printed pins on the lower section top face (hexagon-flat directions, clear of grooves) and 4.4 mm blind holes in the upper bed face; still two upright prints, no supports intended. Pin test watched fail first; validator checks pins/holes and lower height +6 mm.
- [x] Variant D holder: D-specific `holder_profile` override in variants/blade_d_spiked.scad (collar on base root, waist in lower opening, 60 mm swell over the 118–176 mm middle root, taper through the bite); grooves at D's contacts ~37–67/117–179/207–243 mm. Added mace.scad assert that joint pins clear the vertex grooves. Test watched fail first.
- [x] Made blade D the main design: D outline and D-placed spindle in mace.scad, bevel guides moved into export.py (`--bevel`), D tests moved into test_mace.py, variants/ folder retired. Validator also width-probes each section's deepest groove (12 mm foam on D left the upper section unprobed).
- [ ] Independent review of the spindle/contact-groove revision.

Intent: model the reference's multi-tapered central blade holder for the existing approximately 3/4-scale child-sized carrying/photo prop. Prefer one piece; user authorizes two stacked pieces split perpendicular to the handle axis if necessary for the A1 mini. Retain separate soft EVA blades and pommel, existing blade dimensions/mount spacing/PVC cut, an adjustable PVC bore, and fit clearances. Crown is printed with a 4 mm-radius rounded tip, recessed 12 mm below the EVA blade tips; guarding is geometry, not impact certification. Do not apply another 0.75 scaling factor: the current 295.275 mm blades already use that scale. The original two-ring print remains available as a lighter alternative; the default assembly now uses the tapered holder.

Context: existing mounting centers are 180 mm apart, each original ring is 16 mm high, making their combined axial envelope 196 mm. Repository has no Git metadata, so Git history/diff/commit workflows are unavailable.

## Verification and review

- Original blade outline, 295.275 mm length, 45/225 mm stations, 34–56/214–236 mm bands, and PVC layout compared against pre-task OpenSCAD metadata: unchanged.
- Final measured STL bounds: lower 53.9378 × 51.9616 × 123.137 mm; upper 53.9378 × 51.9616 × 123.129 mm. Complete holder is 246.266 mm tall (nominal 246.275; rounded-tip tessellation). Bore diameter 27.17 mm; full-depth pipe cavity has 1 mm axial slack then a 45° ceiling. Split is transverse at blade-local 160.1375 mm; nominal crown tip 283.275, EVA tip 295.275.
- Actual foam/holder CAD intersection is empty with a 0.01 mm radial offset to exclude intended root-face contact (CGAL otherwise keeps zero-volume contact sheets).
- Final gate: `export.py --check` and all 30 unittests pass (217.162 seconds); log `/tmp/sauron-hex-crown-final-gates.Cami3M.log`. New hexagon/crown and wrong-width checks were watched fail before their fixes. Initial full run exposed a false-positive width probe where a stretched hexagon lacked wall stock; corrected the stock condition, then reran the complete suite green.
- Independent reviewer: Paseo `6db5858f-d7a3-4bfe-a894-d1bd5f879ac8`, verified `claude-opus-5-5`, `max`, Plan Mode. First snapshot `/tmp/sauron-holder-review.OtkZR3` completed; accepted findings: F1 orientation instructions, F2 width validation, F3 wall wording. Reviewer's private plan-file/ExitPlanMode attempt reconciled by sending read-only final-text instruction; terminal status idle with no permissions. No project/snapshot edits occurred.
- Focused final re-review uses the same model/effort/run and pins `/tmp/sauron-hex-crown-review.aWhLY2`; pending, not yet a clean final verdict. Runner inherits live CWD; reviewer explicitly scoped to each absolute snapshot.
- No slicer trial or physical print, fit, weight, glue-retention or carrying test performed.

## Separate follow-ups

- Earlier approved spec/plan/progress documents still carry stale execution status; baseline owner/reviewer informed. Baseline was independently reviewed clean before this holder change.
- Other session reports an unanswered packed single-sheet split-blade-template request; that is separate from this task, which intentionally leaves blade/pattern geometry unchanged.
- Earlier reviewer also found the legacy ring/coupon `_mesh` gate can accept narrower-than-metadata slots because it lacks an inside-edge probe. The new holder gate now checks both sides and rejects wrong widths; legacy ring/coupon strengthening remains a separate follow-up. Always physically test real foam and pipe in the coupon.

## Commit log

2026-10-04 Sauron mace cosplay project: SCAD model, paper pattern, print holders, variants
    [adapter.stl, blade_a_drawing.scad, blade_b_sturdy.scad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]
2026-10-06 Holder: reference spindle, contact-only grooves, joint pins, variant D fit
    - Reshape the tapered holder to the drawing's 380 mm core spindle (collar,
    waist, single 60 mm hexagonal swell, long taper) with a pointed crown.
    - Cut blade grooves only where each blade's inner edge meets the core
    (radial shadow of blade_inner_edge) instead of full-length channels.
    - Add three printed alignment pins / blind holes at the two-piece joint.
    - Variant D: D-specific holder_profile placing the swell over its middle
    root and the taper through the bite; per-variant blade/holder clearance test.
    - Narrow default slot clearance to 0.3 mm (10.3 mm slots for 10 mm foam).
    - Regenerate main and variant patter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
    [adapter.stl, fit-coupon.stl, holder-lower.stl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]
2026-10-06 Remove blade variants A, B and C; keep D as the chosen design
    - Delete the a-drawing, b-sturdy and c-hybrid sources and generated folders,
    and the A-D comparison image.
    - Point export_variants.py and test_variants.py at D only.
    - Rewrite variants/README.md for D; regenerate D's outputs (geometry unchanged).
    [adapter.stl, blade_a_drawing.scad, blade_b_sturdy.scad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]
2026-10-06 Make blade D the main design
    - mace.scad: blade D outline (Bezier/arc helpers) and the D-placed holder
    spindle replace the original blade and profile; D's band checks replace the
    original-blade stock asserts.
    - export.py: green bevel guides on every pattern sheet (--bevel MM), moved
    from the retired variant exporter; width probes also cover each section's
    deepest groove so 12 mm foam on D's slimmer upper section is still verified.
    - test_mace.py: D profile/openings, D holder shape and bevel-guide tests.
    - Retire variants/; main patterns/ and prints/ are now D (STL geometry
    identical to the former variants/d-spiked outputs).
    - README/SOURCES/TODO updated; previews regenerated.
    Co-A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
    [adapter.stl, blade_d_spiked.scad, blade_shapes.scad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]
